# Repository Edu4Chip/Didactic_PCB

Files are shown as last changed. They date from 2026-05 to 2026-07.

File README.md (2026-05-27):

# Didactic PCB
This repository includes design files and documentation for Didactic PCBs and software for the power management microcontroller on the PCB.

## Folders
Doc: All documentation is gathered within this folder.
PCBs: KiCad projects Didactic main and wire bond PCBs.
PM_MCU_software: STM32CubeIDE project for the power management microcontroller on the PCB.

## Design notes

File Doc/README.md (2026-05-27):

# Didactic PCB V1.0 user guide 
This repository includes design files and documentation for Didactic PCBs and software for the power management microcontroller on the PCB.

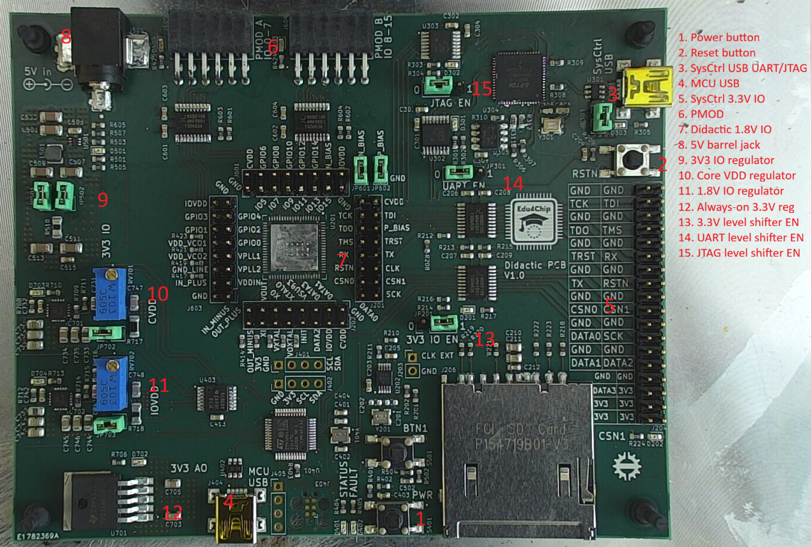
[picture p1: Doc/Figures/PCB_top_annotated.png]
 

## Power and start-up
The Didactic PCB requires external 5V source to function. The 5V can be inserted from a 5.5 mm x 2.1 mm barrel jack or from the SysCtrl Mini-USB port. Only one of these methods should be used at once. If the barrel jack and the SysCtrl Mini-USB port are used at the same time, then JP303 should be opened to disconnect the 5V power from the Mini-USB port.

### Status LED
After 5V power has been provided to the board, an LED (D303) near the SysCtrl Mini-USB port should be lit to indicate that power is being provided. LED (D702) should also be lit to indicate that always-on 3.3 V is being regulated. Finally, the Status LED (D401) should slowly blink to indicate that the microcontroller on the board is ready, and the rest of the board can be powered by pressing the PWR button (S401). After pressing the Power button, the microcontroller will enable 3.3V IO, 1.8V IO and 0.9V Core power rails and start the clock generator and finally release the reset for the Didactic chip. Successful start-up is indicated by the STATUS LED being lit and not blinking. An LED near each power rail’s source will also be lit to indicate that the power rails are enabled. 

|STATUS LED pattern  |Pattern meaning |
|---|---|
|Slowly blinking |Board is powered, but Didactic power is off |
|Rapid blinking |Didactic power is on, but fault monitoring is disabled |
|Fully on |Didactic is powered and clock enabled |

### Power monitoring
The power rails are always monitored for failure (Unless fault monitoring has been disabled). The power rails will fail if their voltage differs too much from the set amount or if too much current is being drawn from them. All power rails are immediately powered down if a failure is noticed in any of the power rails. Failure is indicated by blinking the Fault LED (D402). The failed power rail is indicated by the blinking pattern of the Fault LED (table 2). After power rail failure, the board can be repowered by pressing the PWR button.

|Fault LED blink count|Failed power rail |
|---|---|
|1 |Core |
|2 |IO |
|3 |3.3V IO |

### Votage adjustment
Voltage of IO and Core power rails can be adjusted with trimmers RV702 and RV701. It is recomended to disable power rail fault checking while adjusting the voltages and set new target voltages for each power rail after adjustment. More information about this can be found under the power monitor MCU section.

If needed, the power regulators can be disconnected from the power rails by removing the jumpers near them (JP703, JP702, JP501 and JP502). This may be needed aduring the first bring-up process for each PCB as the power rail voltages may be set incorrectly. If the Didactic chip is assembled on the PCB before bring-up, the power regulators must be disconnected and adjusted. 

## IO
### SysCtrl 3.3V IO
All SysCtrl IOs are level shifted to 3.3V and available on header J204. The signals are level shifted using bidirectional auto direction sensing level shifters. The level shifters must be enabled using the 3V3 IO EN jumper. Because of a design mistake, the level shifters are enabled when the jumper is set to 0 and disabled when the jumper is set to 1. LED D201 near the jumper will indicate when the level shifters are enabled. Level shifted SPI signals are also connected to an SD card socket.

JTAG and UART signals are also level shifted using separate unidirectional level shifters and connected to FT2232HQ USB converter. These level shifters can be enabled with UART EN (JP301) and JTAG EN (JP302) jumpers. Pinout for the FT2232HQ is shown below.

|FT2232HQ pin |Net |
|---|---|
|ADBUS0 |TCK |
|ADBUS1 |TDI |
|ADBUS2 |TDO |
|ADBUS3 |TMS |
|BDBUS0 |TX (Didactic RX) |
|BDBUS1 |RX (Didactic TX) |

### Didactic 1.8V IO
All Didactic 1.8V IO is directly accessible on pin headers J201, J202, J601 and J603. All analog pins 32-50 of Didactic are connected to ground using 0-ohm resistors. N BIAS and P BIAS are connected to ground using JP601 and JP602 jumpers.

### PMOD
GPIO signals 0-15 of the Didactic are connected to two PMOD (PMOD A and PMODB) connectors and level shifted to 3.3V using bidirectional auto direction sensing level shifters. These level sifters are always enabled. PMOD connector IO signal pinouts are shown below.

PMOD A pinoout:
|Didactic |PMOD A |
|---|---|
|GPIO0 |IO1 |
|GPIO1 |IO2 |
|GPIO2 |IO3 |
|GPIO3 |IO4 |
|GPIO4 |IO5 |
|GPIO5 |IO6 |
|GPIO6 |IO7 |
|GPIO7 |IO8 |

PMOD B pinoout:
|Didactic |PMOD B |
|---|---|
|GPIO8 |IO1 |
|GPIO9 |IO2 |
|GPIO10 |IO3 |
|GPIO11 |IO4 |
|GPIO12 |IO5 |
|GPIO13 |IO6 |
|GPIO14 |IO7 |
|GPIO15 |IO8 |

## Power monitor MCU
Microcontroller on the board is used to monitor and sequence the power rails and control the clock generator. The Didactic can be started by pressing the PWR button or the start-up process can be controlled using the microcontrollers virtual COM port. The COM port can be accessed by connecting a Mini-USB cable to the MCU USB port.

### Virtual COM port
Any virtual terminal software can be used to connect to Virtual COM port. Baud rate can also be freely chosen.

The microcontroller will continuously print the voltage and current of all the power rails. The virtual terminal window should be made big enough so that a full line of text can fit without line changes. Commands can be typed into the virtual terminal, and all commands must be ended by pressing enter. Pressing enter will also always reprint the command list. Configuration for all power rails is shown at the bottom of the terminal and the bottom most line is updated three times a second and it shows the current voltage and power consumption of the power rails.

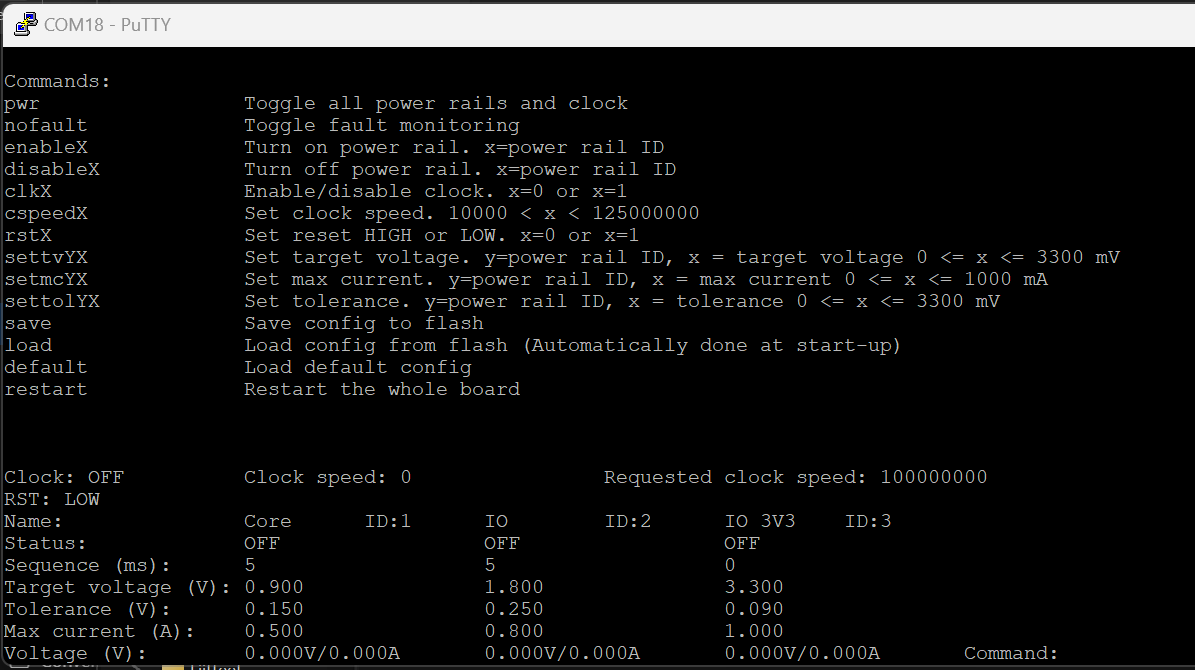
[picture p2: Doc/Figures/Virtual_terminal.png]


### Commands
Power rails and the clock can be controlled by writing commands to the virtual terminal. All supported commands are shown below.

|Command |Parameters |Explanation |
|---|---|---|
|pwr | |Turns on/off all the power rails and clock. Same as pressing the PWR button |
|nofault | |Disables/enables fault checking for all power rails. Status LED will blink quickly when power is enabled, and fault checking is disabled |
|enableX |X = power rail ID |Enabled power rail* |
|disableX |X = power rail ID |Disable power rail* |
|clkX |X = 0 or X = 1 |Enabled or disable clock. 1 = enable |
|cspeed |10000 < X < 125000000 |Set requested clock speed. clk1 command must be sent after this command to enable clock with requested speed |
|rstX |X = 0 or X = 1 |Set Didactic reset LOW or HIGH, LOW = reset |
|settvYX |Y = power rail ID, 0 mV <= X <= 3300 mV|Set power rail’s target voltage |
|setmcYX |Y = power rail ID, 0 mA <= X <= 1000 mA|Set power rail’s maximum current |
|settolYX |Y = power rail ID, 0 mV <= X <= 3300 mV|Set power rail’s tolerance to voltage difference between target and actual voltage |
|save | |Save current config to Flash |
|load | |Load config from flash |
|default | |Load default config |
|restart | |Shutdown all power rails and restart the MCU |

*IO and Core power rails source their power from 3.3V IO power rails, so they cannot be powered before 3.3V IO power rails. IO and Core can be enabled before 3.3V IO power rails but they will be powered only after 3.3V IO has been powered. 

### Programming
The microcontroller can be programmed using ST-LINK debugger using SWD interface. This can be done using 4-pin pin header (J405) or 6-pin TC2030 Tag-Connect cable.

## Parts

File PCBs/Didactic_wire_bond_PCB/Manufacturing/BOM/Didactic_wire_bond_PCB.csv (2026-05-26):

Reference | Qty | Value | DNP | Exclude from BOM | Exclude from Board | Footprint | Datasheet
C101,C102,C103,C104,C105,C106,C107,C108 | 8 | 100n |  |  |  | Capacitor_SMD:C_0402_1005Metric | ~
J101 | 1 | 2118714-2 |  |  |  | SoC_Hub_kicad_footprint_library:TE_2118714-2
J201,J202,J601,J603 | 4 | Conn_02x08_Odd_Even | DNP |  |  | Connector_PinHeader_2.54mm:PinHeader_2x08_P2.54mm_Vertical | ~
U101 | 1 | ~ |  |  |  | SoC_Hub_kicad_footprint_library:Didactic_WB

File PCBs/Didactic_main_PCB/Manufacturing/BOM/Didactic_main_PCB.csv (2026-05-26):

Reference | Value | Footprint | Qty | DNP | MANUFACTURER_PART_NUMBER
C201,C202 | 4p | Capacitor_SMD:C_0603_1608Metric | 2 | DNP
C203,C204,C205,C206,C207,C208,C209,C212,C301,C302,C303,C304,C307,C308,C310,C311,C312,C314,C316,C317,C318,C319,C320,C321,C403,C404,C405,C406,C407,C408,C409,C410,C413,C502,C505,C515,C601,C602,C603,C604,C711,C712,C713,C714,C715,C716,C717,C718,C721,C722,C723,C724,C725,C726,C727,C728,C731,C743 | 100n | Capacitor_SMD:C_0603_1608Metric | 58 |  | GPC0603104
C210,C211,C703,C705,C719,C720,C729,C730,C734,C735,C737,C738,C740,C741,C745,C746,C747,C748 | 10u | Capacitor_SMD:C_0805_2012Metric | 18 |  | GPC0805106-25
C305,C306,C401,C402 | 10p | Capacitor_SMD:C_0603_1608Metric | 4 |  | GPC0603100
C309,C313,C315,C411,C412 | 4.7u | Capacitor_SMD:C_0603_1608Metric | 5 |  | GPC0603475-10
C501,C503,C507,C509,C511,C513 | 22u | Capacitor_SMD:C_1206_3216Metric | 6 |  | CL31A226KAHNNNE
C732,C742 | 10n | Capacitor_SMD:C_0603_1608Metric | 2 |  | GPC0603103
C733,C736,C739,C744 | 47u | Capacitor_SMD:C_0805_2012Metric | 4 |  | GPC0805476-6.3
D201,D202,D301,D302,D303,D401,D402,D403,D404,D501,D702,D703,D704 | LED | LED_SMD:LED_0603_1608Metric | 13 |  | APHD1608LSURCK
IC201,IC202,IC601,IC602 | NXB0108PWJ | SoC_Hub_kicad_footprint_library:NXB0108PWJ | 4 |  | NXB0108PWJ
IC701,IC702 | AP7179DSKZ20-13 | SoC_Hub_kicad_footprint_library:QFN50P350X350X80-21N-D | 2 |  | AP7179DSKZ20-13
J201,J202,J601,J603 | Conn_02x08_Odd_Even | Connector_PinHeader_2.54mm:PinHeader_2x08_P2.54mm_Vertical | 4 |  | 77313-101-16LF
J203 | Conn_01x02_Pin | Connector_PinHeader_2.54mm:PinHeader_1x02_P2.54mm_Vertical | 1 |  | 61300211121
J204 | Conn_02x18_Odd_Even | Connector_PinHeader_2.54mm:PinHeader_2x18_P2.54mm_Vertical | 1 |  | 77313-101-36LF
J206 | 10067847-001RLF | AMPHENOL_10067847-001RLF | 1 |  | 10067847-001RLF
J301,J404 | 690-005-299-043 | Headsail_footprints:EDAC_690-005-299-043 | 2 |  | 690-005-299-043
J401,J402 | Conn_01x04_Pin | Connector_PinHeader_2.54mm:PinHeader_1x04_P2.54mm_Vertical | 2 | DNP | 77311-424-04LF
J405 | Conn_01x04_Pin | Connector_PinHeader_2.54mm:PinHeader_1x04_P2.54mm_Vertical | 1 |  | 77311-424-04LF
J501 | PJ-036AH-SMT-TR | Headsail_footprints:CUI_PJ-036AH-SMT-TR | 1 |  | PJ-036AH-SMT-TR
J604,J605 | SSW-106-02-T-D-RA | SoC_Hub_kicad_footprint_library:SAMTEC_SSW-106-02-T-D-RA | 2 |  | SSW-106-02-T-D-RA
JP201,JP301,JP302 | Jumper_3_Open | Connector_PinHeader_2.54mm:PinHeader_1x03_P2.54mm_Vertical | 3 |  | 61300311121
JP303,JP501,JP502,JP601,JP602,JP702,JP703 | Jumper_2_Bridged | Connector_PinHeader_2.54mm:PinHeader_1x02_P2.54mm_Vertical | 7 |  | 61300211121
L501 | 74404032015 | SoC_Hub_kicad_footprint_library:WE-LQS_3015 | 1 |  | 74404032015
R201,R202,R206,R208,R215,R216,R302,R304,R306,R307,R310,R402,R403,R503,R504,R505,R507,R603,R604,R708,R709,R711,R712,R714,R715,R716 | 10k | Resistor_SMD:R_0603_1608Metric | 26 |  | GPR060310K
R203,R204,R205,R207,R218,R219,R220,R221,R222,R223 | 56k2 | Resistor_SMD:R_0603_1608Metric | 10 |  | CPF0603F56K2C1
R209,R213,R214,R217,R224,R301,R303,R305,R309,R311,R312,R401,R404,R405,R424,R425,R501,R502,R601,R602,R706,R710,R713 | 1k | Resistor_SMD:R_0603_1608Metric | 23 |  | GPR06031K
R210 | 0 | Resistor_SMD:R_0603_1608Metric | 1 | DNP | GPR06030R
R211,R212,R406,R407,R408,R409,R410,R411,R412,R413,R414,R415,R416,R417,R418,R419,R420,R421,R422,R423 | 0 | Resistor_SMD:R_0603_1608Metric | 20 |  | GPR06030R
R308 | 12k | Resistor_SMD:R_0603_1608Metric | 1 |  | GPR060312K
R510,R718 | 16m | Resistor_SMD:R_1206_3216Metric | 2 |  | ERJ-8CWFR016V
R605 | 45.3k | Resistor_SMD:R_0603_1608Metric | 1 |  | CPF0603F45K3C1
R717 | 33m | Resistor_SMD:R_1206_3216Metric | 1 |  | ERJ-8CWFR033V
RV701,RV702 | PV36W103C01B00 | SoC_Hub_kicad_footprint_library:TRIM_PV36W103C01B00 | 2 |  | PV36W103C01B00
S201,S401,S501 | TL3301TF160QG | Headsail_footprints:SW_TL3301TF160QG | 3 |  | TL3301TF160QG
U201 | ~ | SoC_Hub_kicad_footprint_library:Didactic_QFN-80_EP_12x12_Pitch0.5mm | 1
U202 | SI5351A-B-GT | SoC_Hub_kicad_footprint_library:MSOP10_SI5351_3X3-0P5_SKY | 1 |  | SI5351A-B-GT
U301,U402 | USBLC6-2SC6 | Package_TO_SOT_SMD:SOT-23-6 | 2 |  | USBLC6-2SC6
U302,U303 | SN74AVC4T774PWR | SoC_Hub_kicad_footprint_library:SOP65P640X120-16N | 2 |  | SN74AVC4T774PWR
U304 | FT2232HQ | Headsail_footprints:QFN50P900X900X100-65N | 1 |  | FT2232HQ
U305 | 93LC56BT_SN | Headsail_footprints:SOIC127P600X175-8N | 1 |  | 93LC56BT/SN
U401 | STM32G431CBT6 | LQFP48-7x7mm | 1 |  | STM32G431CBT6
U403 | INA4180A4IPWR | Headsail_footprints:SOP65P640X120-14N | 1 |  | INA4180A4IPWR
U501 | TPS564255DRLR | TPS564242DRLR_TEX | 1 |  | TPS564255DRLR
U701 | TPS7A4533KTTR | SoC_Hub_kicad_footprint_library:VREG_TPS79625KTTR | 1 |  | TPS7A4533KTTR
Y201,Y401 | ECS-250-8-33B-CKM-TR | SoC_Hub_kicad_footprint_library:XTAL_ECS-250-8-33B-CKM-TR | 2 |  | ECS-250-8-33B-CKM-TR
Y301 | ECS-120-8-33-JGN-TR3 | Headsail_footprints:XTAL_ECS-120-8-33-JGN-TR3 | 1 |  | ECS-120-8-33-JGN-TR3

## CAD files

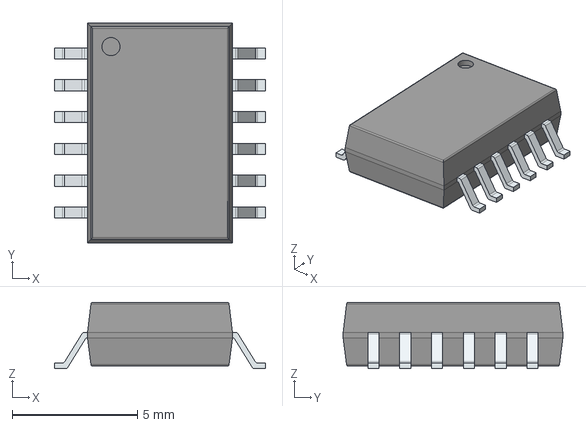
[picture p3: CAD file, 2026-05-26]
PCBs/Didactic_component_library/3D/218-6LPST.stp
8.44 x 8.79 x 2.65 mm
PinsArrayLR

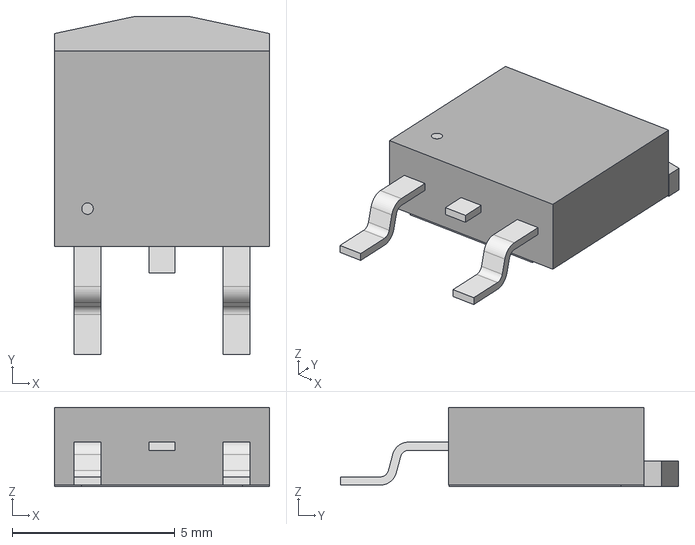
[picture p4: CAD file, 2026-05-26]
PCBs/Didactic_component_library/3D/TO-252-3_6P6X6P1_DIO.step
6.60 x 10.4 x 2.44 mm

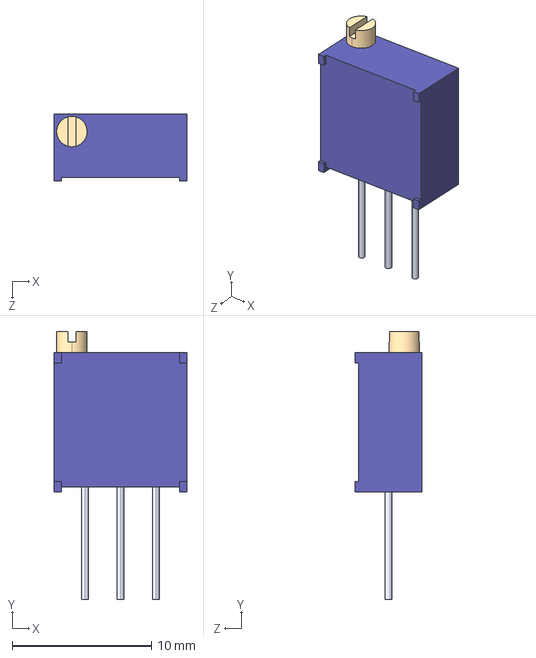
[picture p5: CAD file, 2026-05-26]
PCBs/Didactic_component_library/3D/PV36W103C01B00.step
9.53 x 19.3 x 4.83 mm

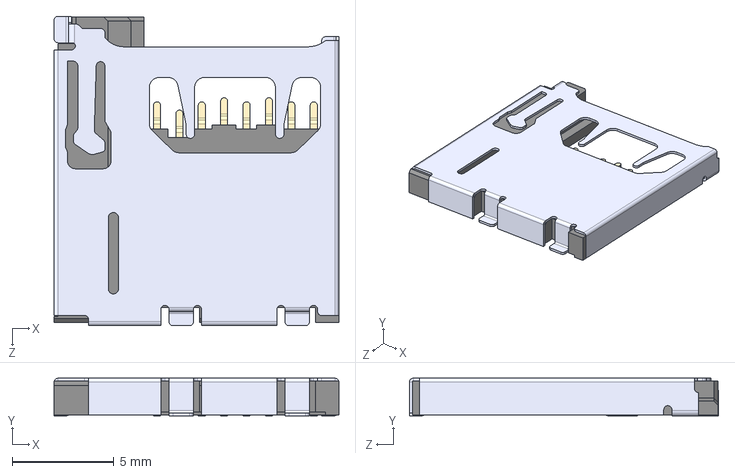
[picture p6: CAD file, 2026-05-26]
PCBs/Didactic_component_library/3D/2908-05WB-MG.step
14.0 x 1.85 x 15.2 mm

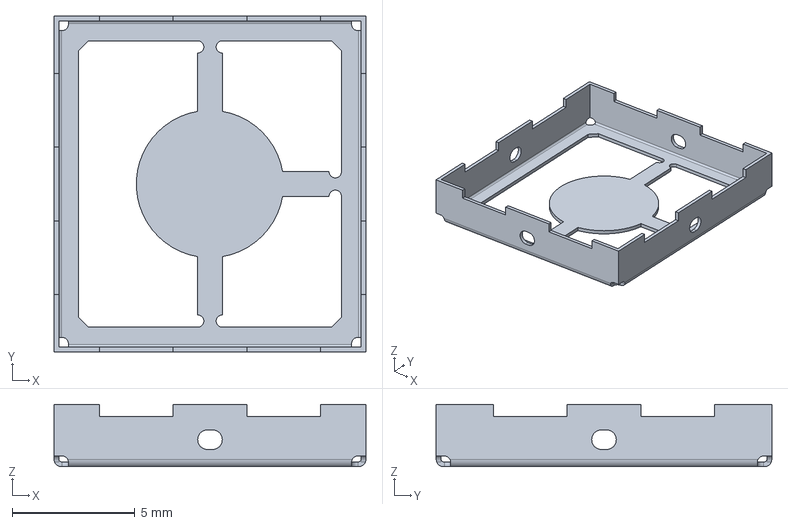
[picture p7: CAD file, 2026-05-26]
PCBs/Didactic_component_library/3D/2118714-2.step
12.7 x 13.7 x 2.54 mm

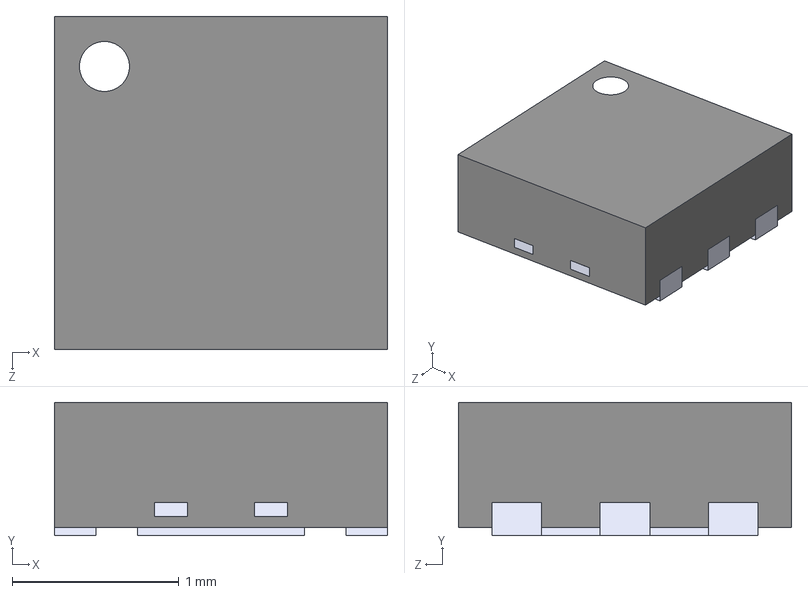
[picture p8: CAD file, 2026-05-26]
PCBs/Didactic_component_library/3D/TLV75709PDRVR.step
2.00 x 0.8 x 2.00 mm

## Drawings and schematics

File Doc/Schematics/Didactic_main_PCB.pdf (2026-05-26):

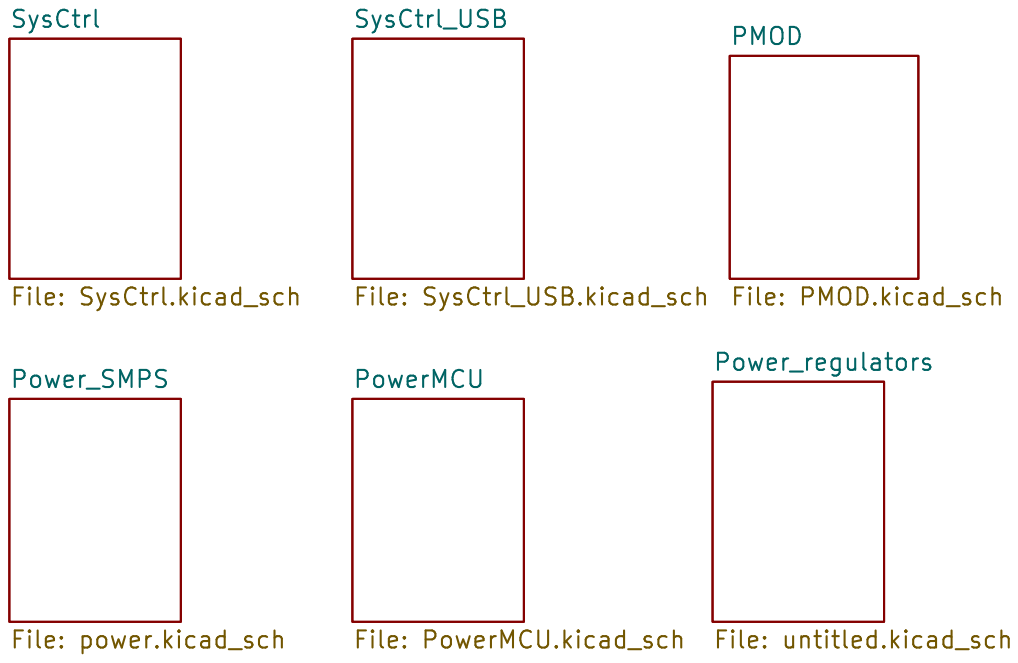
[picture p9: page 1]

Roope Keskinen / roope.r.keskinen@tuni.fi
File: Didactic.kicad_sch Sheet: / TAU

Id: 1/7 Title: Didactic PCB

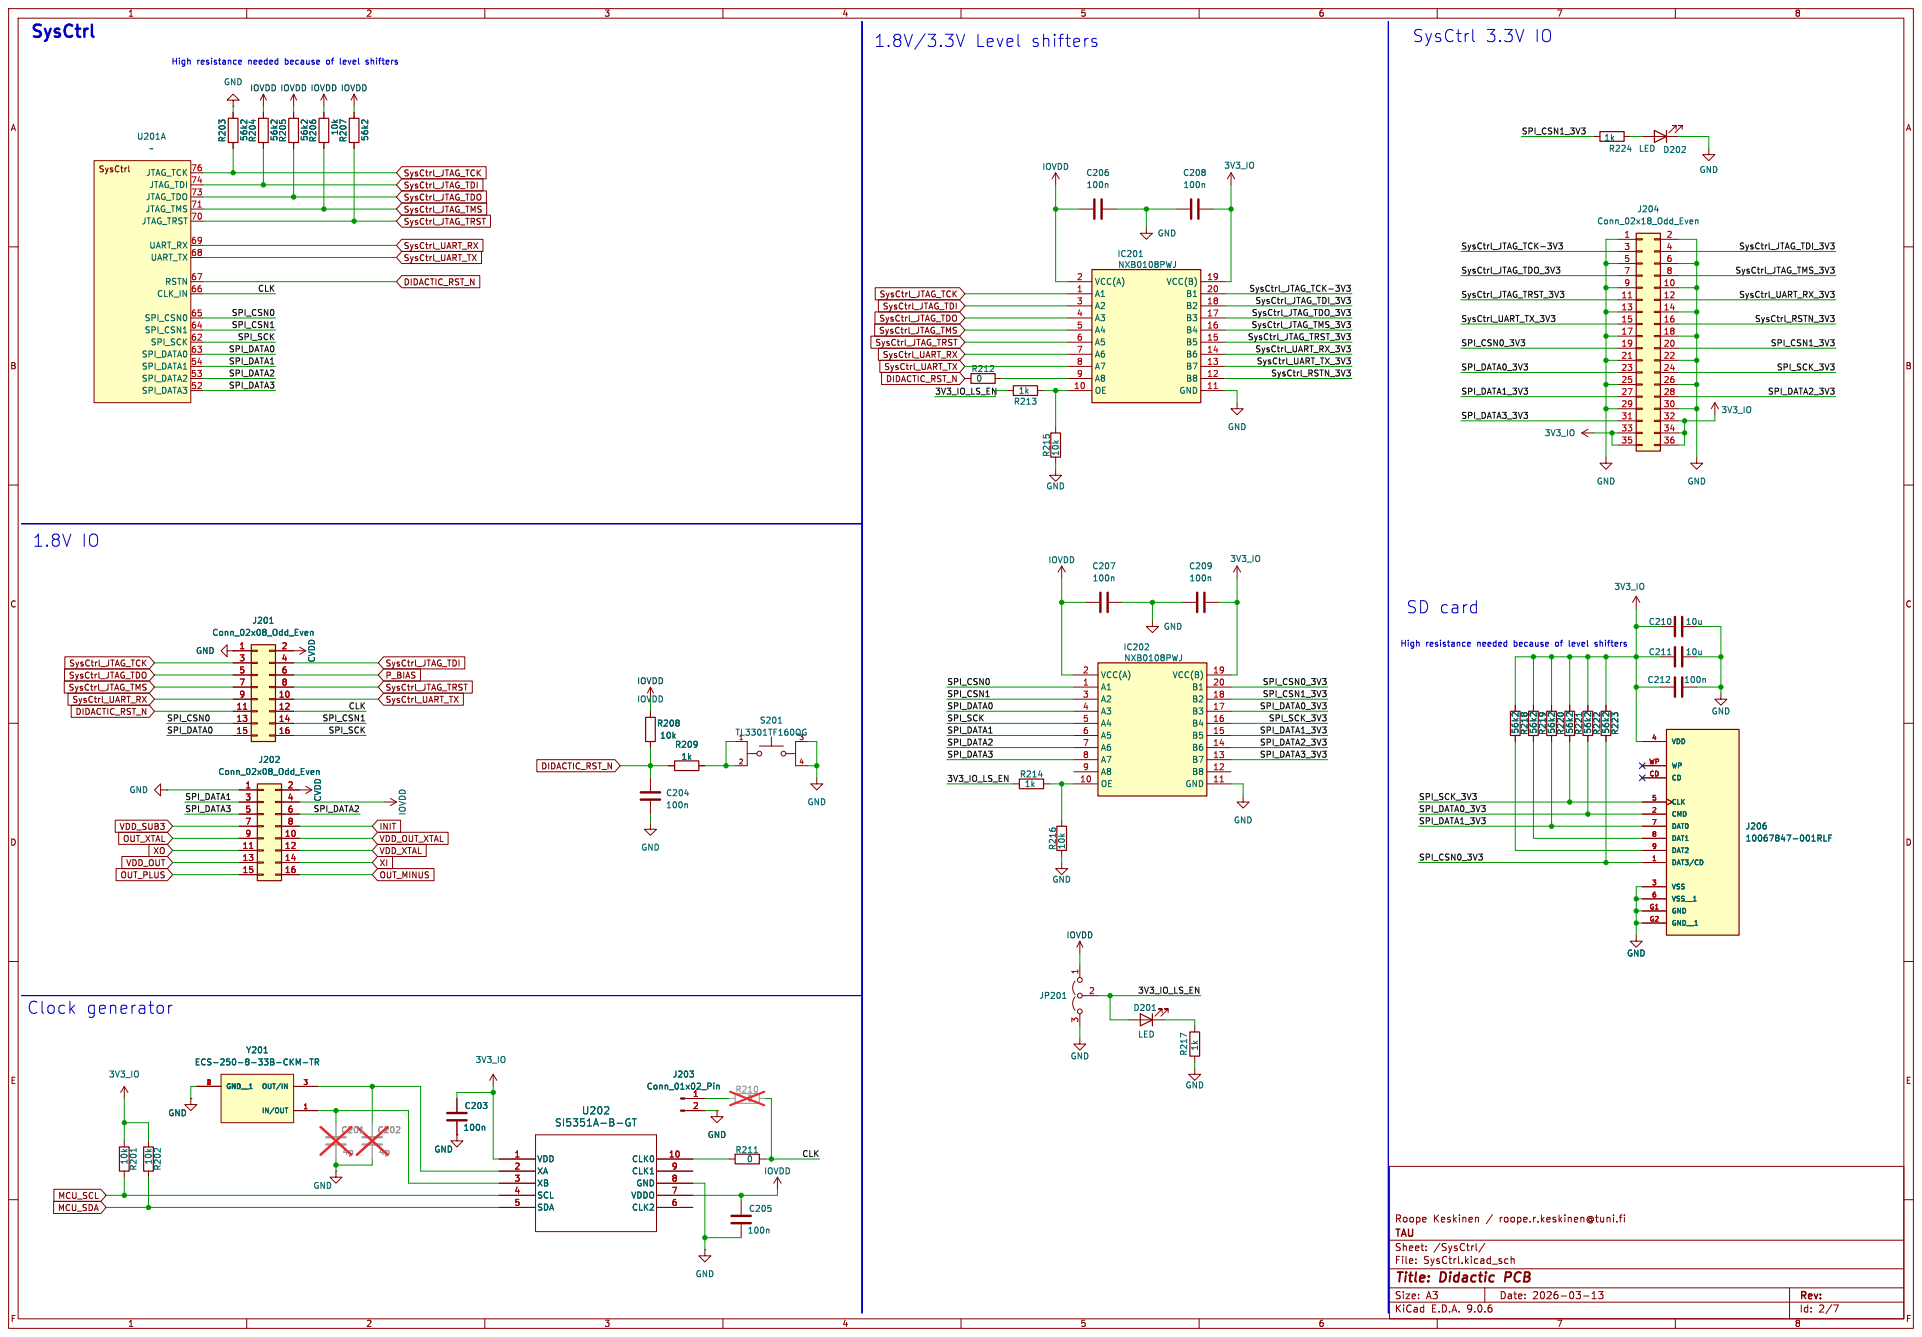
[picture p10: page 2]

File: SysCtrl.kicad_sch Sheet: /SysCtrl/ TAU

Id: 2/7 Title: Didactic PCB

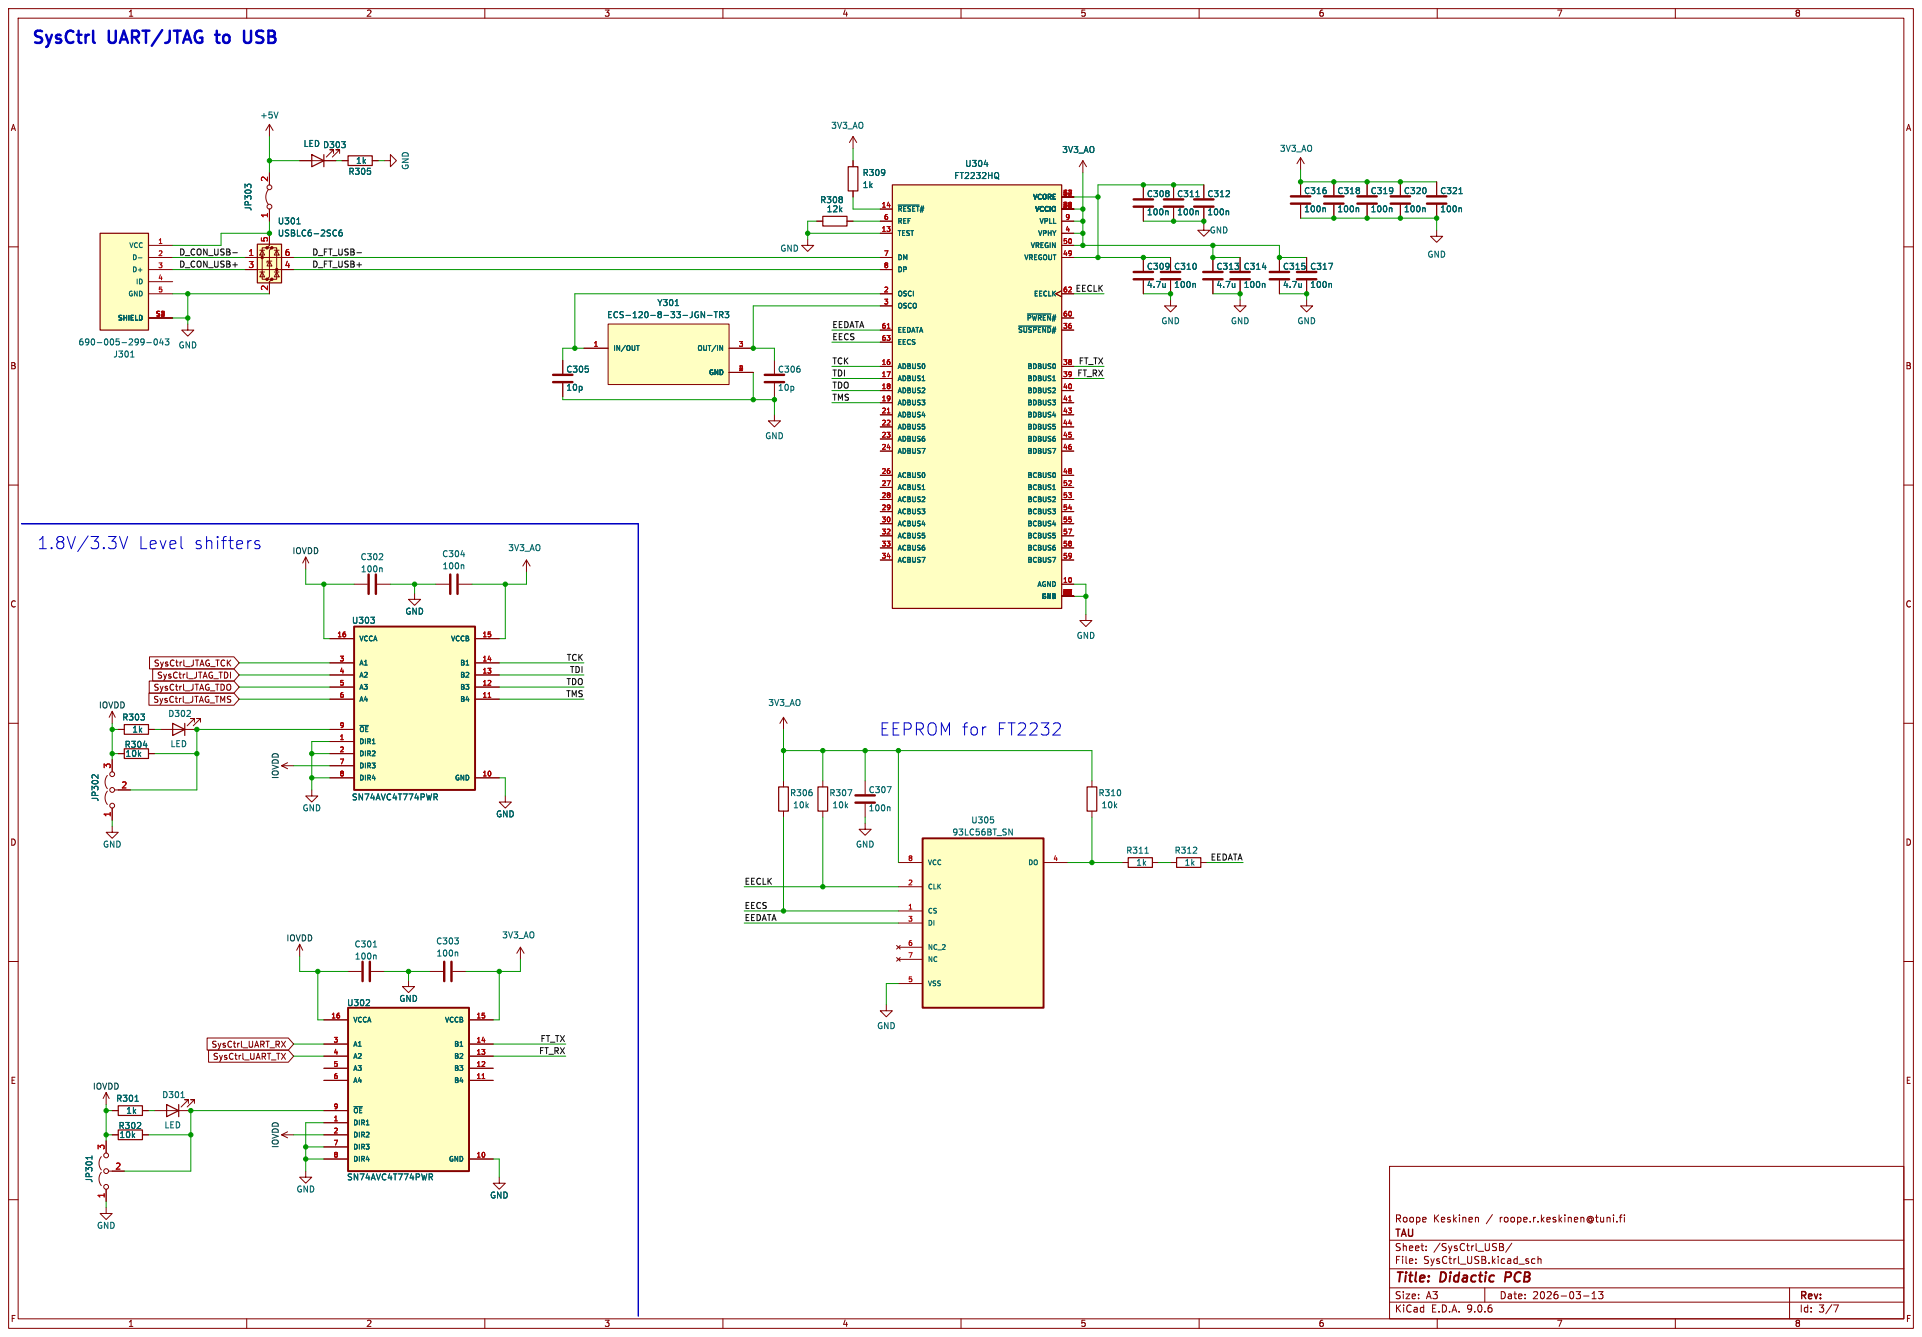
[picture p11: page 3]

SysCtrl UART/JTAG to USB

Id: 3/7 Title: Didactic PCB

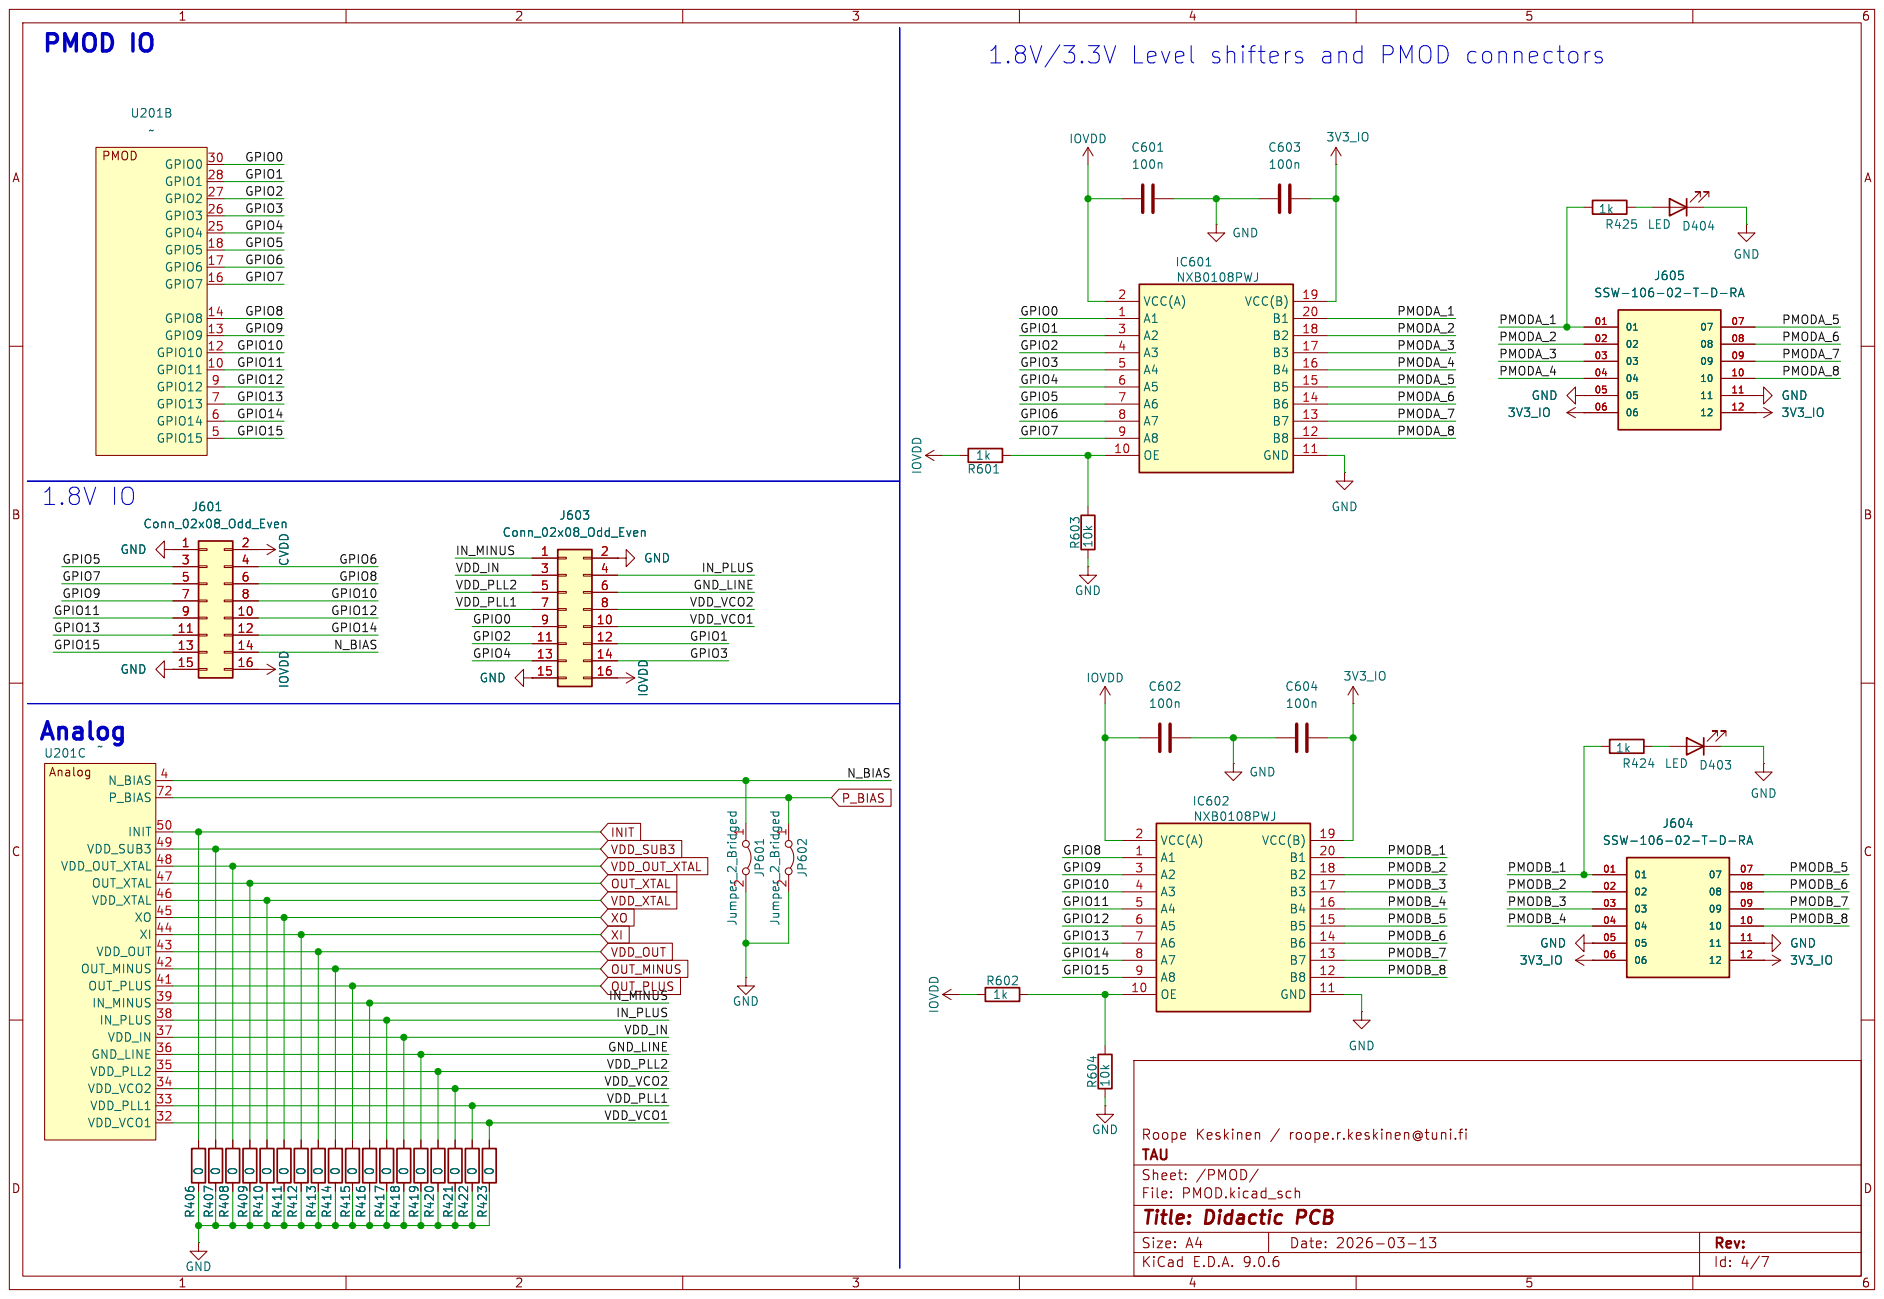
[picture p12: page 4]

0 GND GND GND R604 10k GND

Roope Keskinen / roope.r.keskinen@tuni.fi
File: PMOD.kicad_sch Sheet: /PMOD/ TAU

Id: 4/7 Title: Didactic PCB

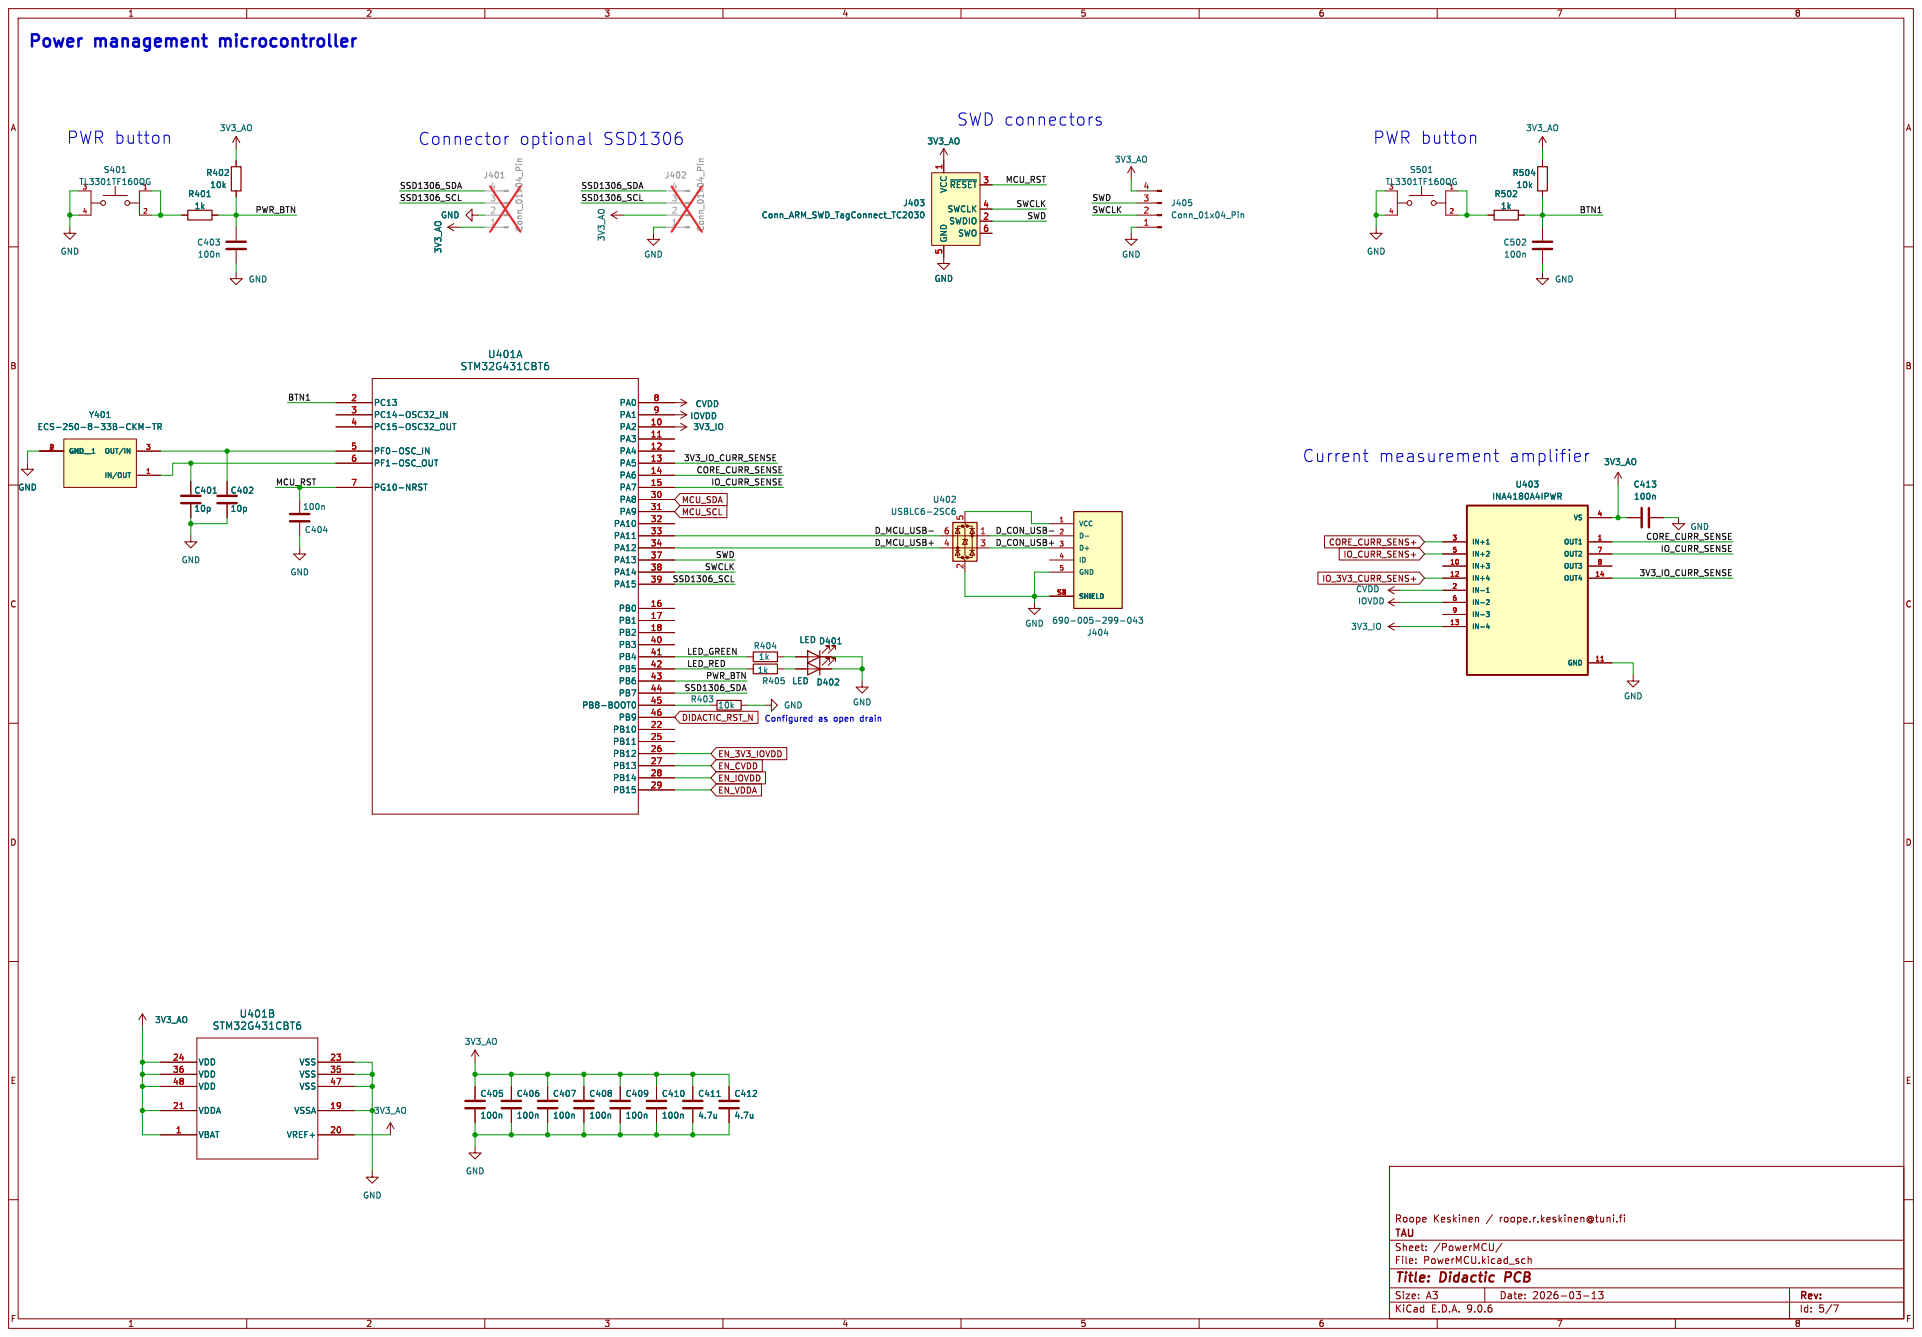
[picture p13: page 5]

5 ~{RESET}3 SWCLK 4 SWDIO 2 SWO 6

Id: 5/7 Title: Didactic PCB

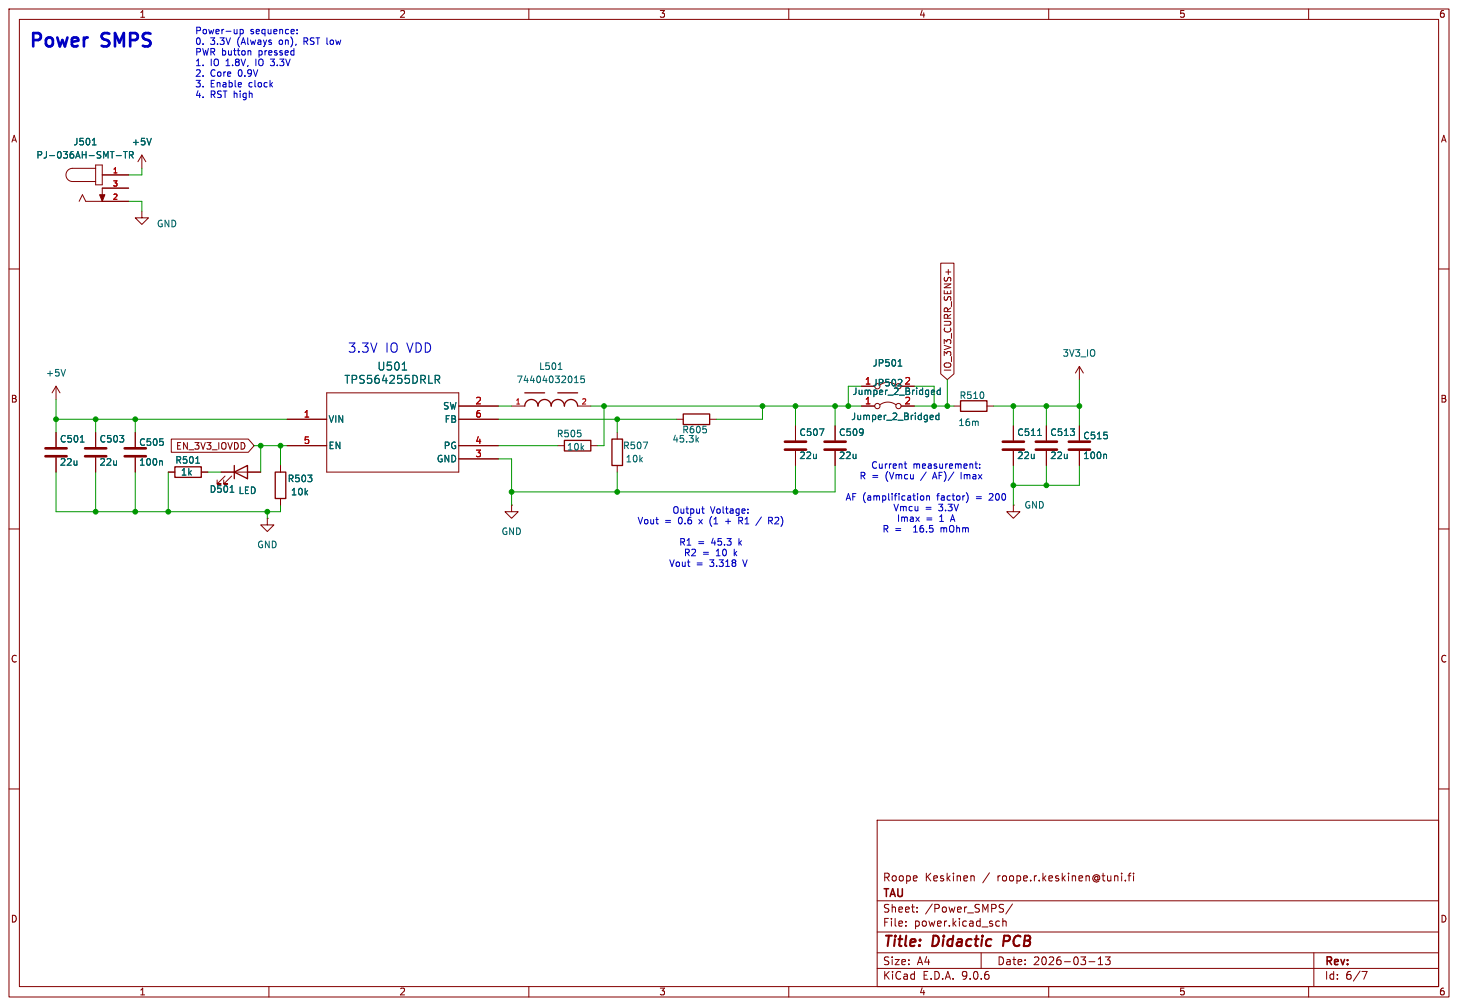
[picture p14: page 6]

PWR button pressed
2. Core 0.9V
3. Enable clock 4. RST high

Output Voltage: Vout = 0.6 x (1 + R1 / R2) R1 = 45.3 k R2 = 10 k Vout = 3.318 V 3.3V IO VDD
22u U501 TPS564255DRLR

Roope Keskinen / roope.r.keskinen@tuni.fi R605

File: power.kicad_sch Sheet: /Power_SMPS/ TAU

Id: 6/7 Title: Didactic PCB

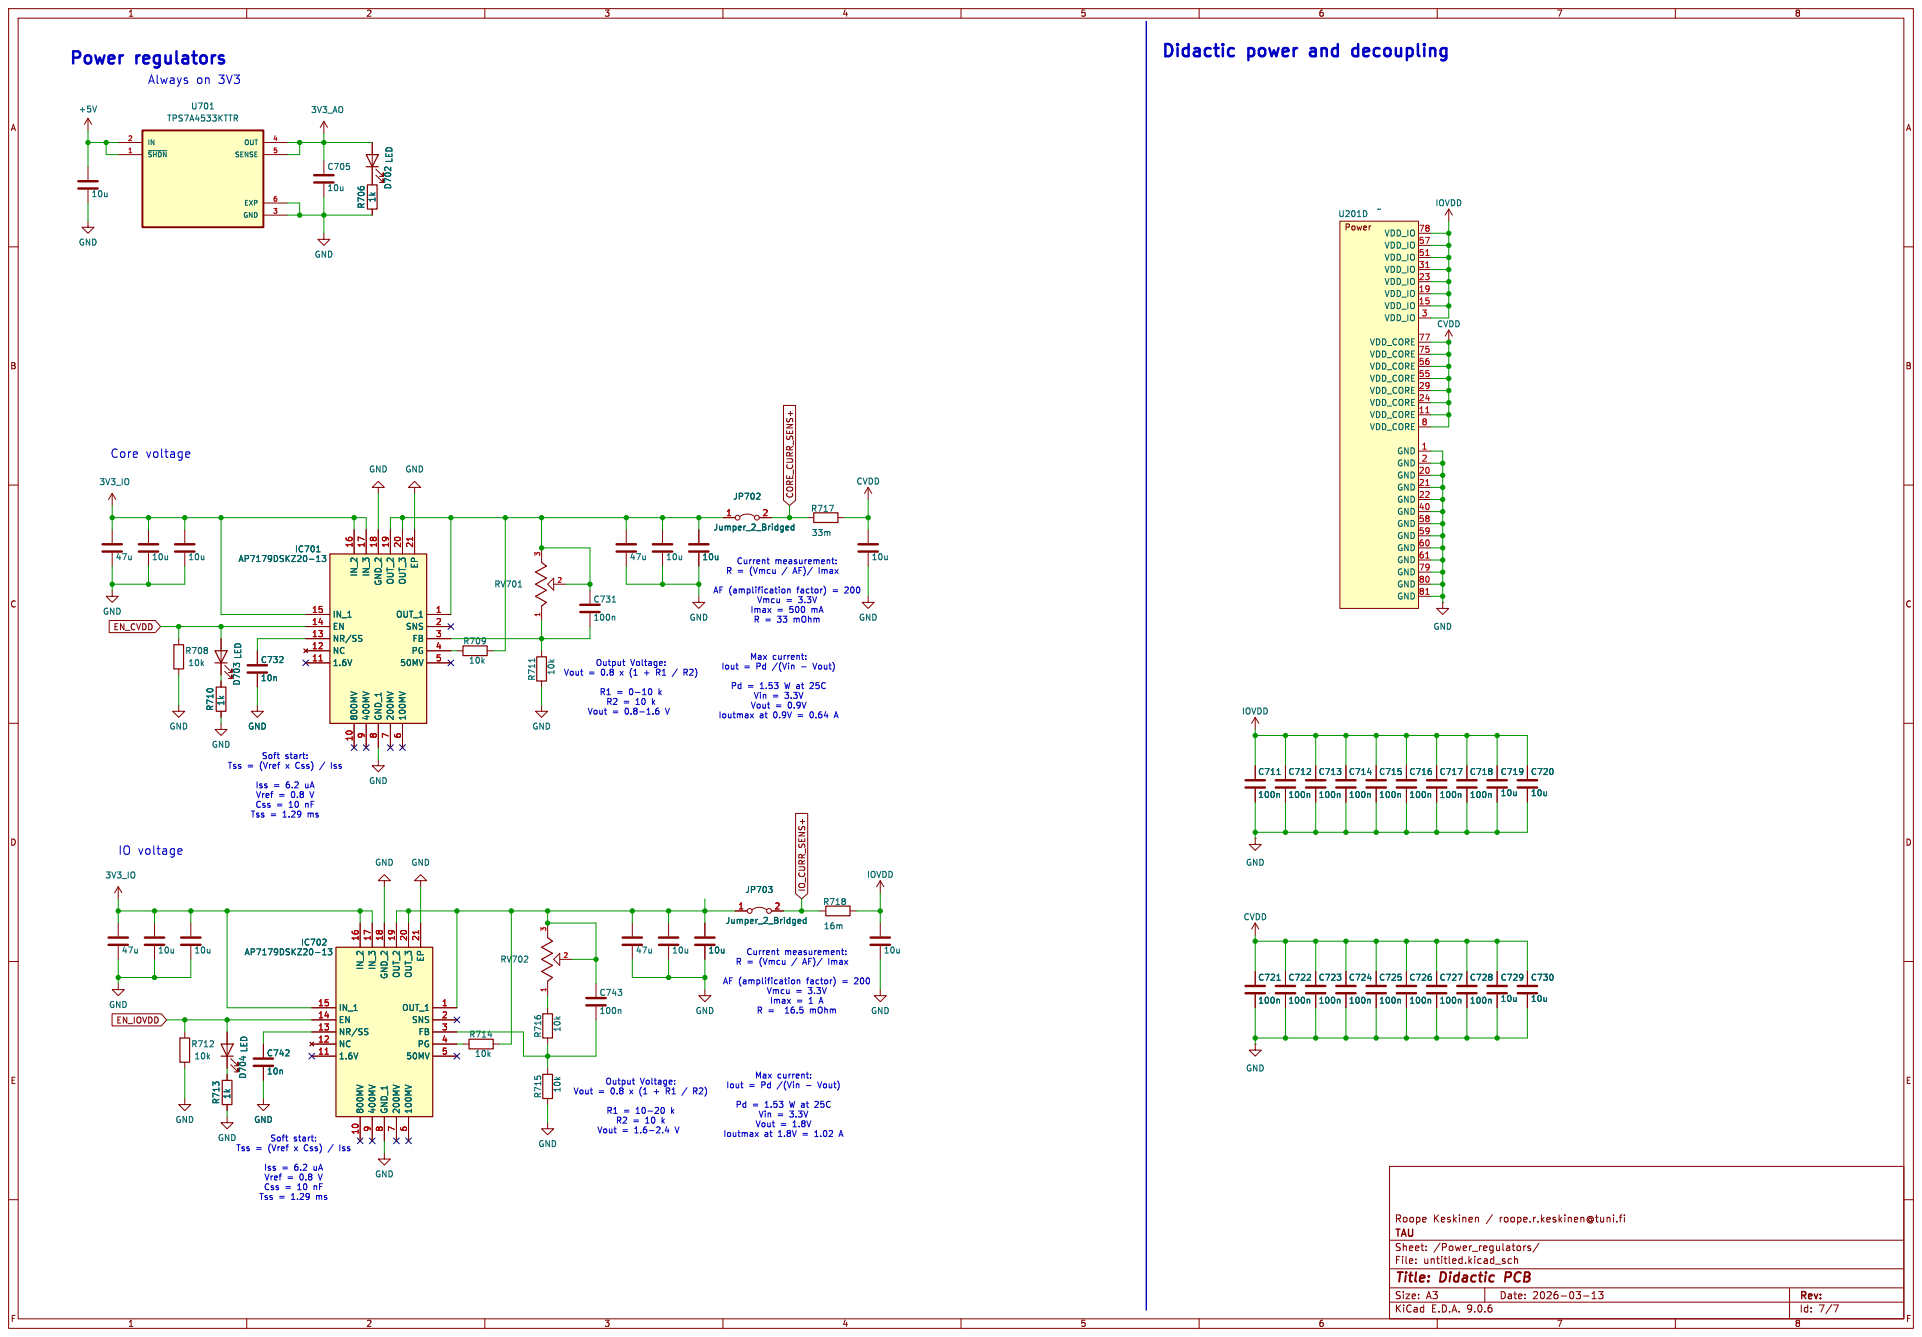
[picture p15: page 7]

Soft start: Tss = (Vref x Css) / Iss

File: untitled.kicad_sch Sheet: /Power_regulators/ TAU

Id: 7/7 Title: Didactic PCB

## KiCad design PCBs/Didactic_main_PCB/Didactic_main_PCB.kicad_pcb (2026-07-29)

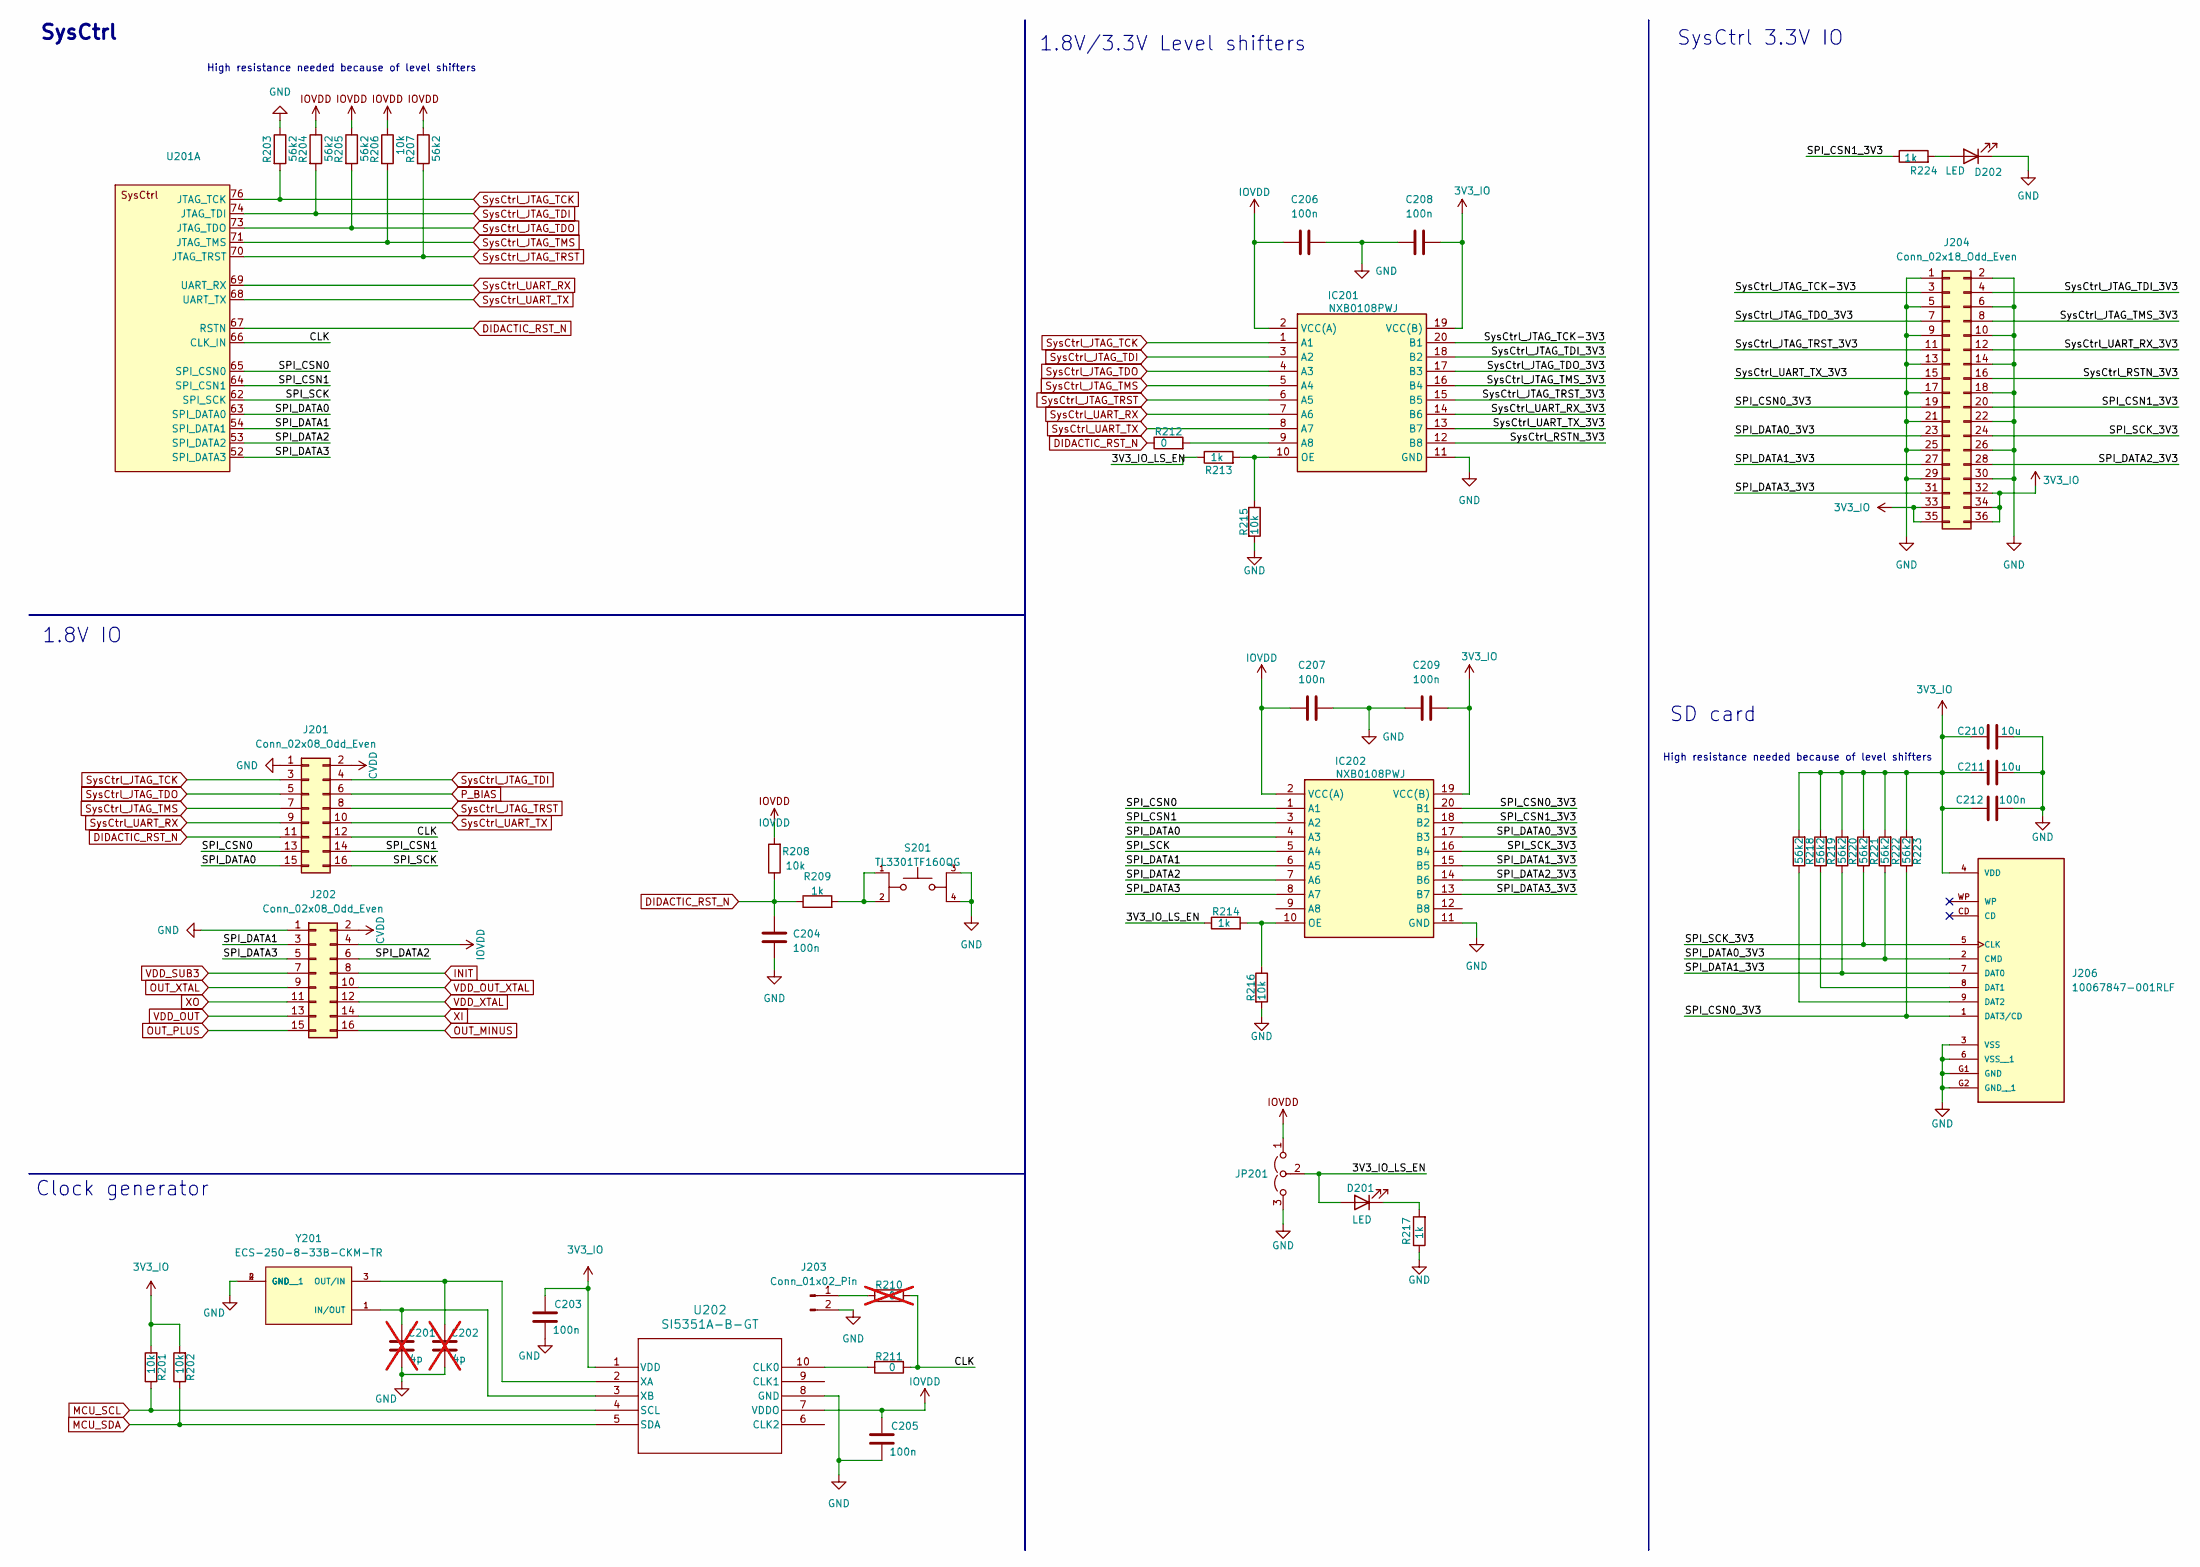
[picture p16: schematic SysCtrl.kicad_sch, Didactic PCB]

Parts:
C201, C202: 4p; C_0603_1608Metric; not fitted
C203, C204, C205, C206, C207, C208, C209, C212: 100n; C_0603_1608Metric; MANUFACTURER_PART_NUMBER GPC0603104
C210, C211: 10u; C_0805_2012Metric; MANUFACTURER_PART_NUMBER GPC0805106-25
D201, D202: LED; LED_0603_1608Metric; MANUFACTURER_PART_NUMBER APHD1608LSURCK
IC201, IC202: NXB0108PWJ; Mouser Part Number 771-NXB0108PWJ
J201, J202: Conn_02x08_Odd_Even; PinHeader_2x08_P2.54mm_Vertical; MANUFACTURER_PART_NUMBER 77313-101-16LF
J203: Conn_01x02_Pin; PinHeader_1x02_P2.54mm_Vertical; MANUFACTURER_PART_NUMBER 61300211121
J204: Conn_02x18_Odd_Even; PinHeader_2x18_P2.54mm_Vertical; MOUSER_PART_NUMBER 77313-101-36LF
J206: 10067847-001RLF; AMPHENOL_10067847-001RLF; PARTREV K
JP201: Jumper_3_Open; PinHeader_1x03_P2.54mm_Vertical; MANUFACTURER_PART_NUMBER 61300311121
R201, R202, R206, R208, R215, R216: 10k; R_0603_1608Metric; MANUFACTURER_PART_NUMBER GPR060310K
R203, R204, R205, R207, R218, R219, R220, R221, R222, R223: 56k2; R_0603_1608Metric; MANUFACTURER_PART_NUMBER CPF0603F56K2C1
R209, R213, R214, R217, R224: 1k; R_0603_1608Metric; MANUFACTURER_PART_NUMBER GPR06031K
R210: 0; R_0603_1608Metric; MANUFACTURER_PART_NUMBER GPR06030R; not fitted
R211, R212: 0; R_0603_1608Metric; MANUFACTURER_PART_NUMBER GPR06030R
S201: TL3301TF160QG; SW_TL3301TF160QG; PARTREV E
U201: Didactic_QFN-80_EP_12x12_Pitch0.5mm
U202: SI5351A-B-GT; MSOP10_SI5351_3X3-0P5_SKY; MANUFACTURER_PART_NUMBER SI5351A-B-GT
Y201: ECS-250-8-33B-CKM-TR; XTAL_ECS-250-8-33B-CKM-TR; MANUFACTURER_PART_NUMBER ECS-250-8-33B-CKM-TR

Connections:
3V3_IO: C203.2, C208.2, C209.2, C210.1, C211.1, C212.1, IC201.19 (VCC(B)), IC202.19 (VCC(B)), J204.32, J204.33, J204.34, J204.35, J204.36, J206.4 (VDD), R201.2, R202.2, R218.2, R219.2, R220.2, R221.2, R222.2, R223.2, U202.1 (VDD); also elsewhere on the board
/SysCtrl/3V3_IO_LS_EN: D201.2 (A), JP201.2 (C), R213.1, R214.1
/SysCtrl/CLK: J201.12, R210.1, R211.1, U201.66 (CLK_IN)
/SysCtrl/SPI_CSN0: IC202.1 (A1), J201.13, U201.65 (SPI_CSN0)
/SysCtrl/SPI_CSN0_3V3: IC202.20 (B1), J204.19, J206.1 (DAT3/CD), R223.1
/SysCtrl/SPI_CSN1: IC202.3 (A2), J201.14, U201.64 (SPI_CSN1)
/SysCtrl/SPI_CSN1_3V3: IC202.18 (B2), J204.20, R224.1
/SysCtrl/SPI_DATA0: IC202.4 (A3), J201.15, U201.63 (SPI_DATA0)
/SysCtrl/SPI_DATA0_3V3: IC202.17 (B3), J204.23, J206.2 (CMD), R222.1
/SysCtrl/SPI_DATA1: IC202.6 (A5), J202.3, U201.54 (SPI_DATA1)
/SysCtrl/SPI_DATA1_3V3: IC202.15 (B5), J204.27, J206.7 (DAT0), R220.1
/SysCtrl/SPI_DATA2: IC202.7 (A6), J202.6, U201.53 (SPI_DATA2)
/SysCtrl/SPI_DATA2_3V3: IC202.14 (B6), J204.28
/SysCtrl/SPI_DATA3: IC202.8 (A7), J202.5, U201.52 (SPI_DATA3)
/SysCtrl/SPI_DATA3_3V3: IC202.13 (B7), J204.31
/SysCtrl/SPI_SCK: IC202.5 (A4), J201.16, U201.62 (SPI_SCK)
/SysCtrl/SPI_SCK_3V3: IC202.16 (B4), J204.24, J206.5 (CLK), R221.1
/SysCtrl/SysCtrl_JTAG_TCK-3V3: IC201.20 (B1), J204.3
/SysCtrl/SysCtrl_JTAG_TDI_3V3: IC201.18 (B2), J204.4
/SysCtrl/SysCtrl_JTAG_TDO_3V3: IC201.17 (B3), J204.7
/SysCtrl/SysCtrl_JTAG_TMS_3V3: IC201.16 (B4), J204.8
/SysCtrl/SysCtrl_JTAG_TRST_3V3: IC201.15 (B5), J204.11
/SysCtrl/SysCtrl_RSTN_3V3: IC201.12 (B8), J204.16
/SysCtrl/SysCtrl_UART_RX_3V3: IC201.14 (B6), J204.12
/SysCtrl/SysCtrl_UART_TX_3V3: IC201.13 (B7), J204.15
CVDD: J201.2, J202.2; also elsewhere on the board
DIDACTIC_RST_N: C204.1, J201.11, R208.1, R209.1, R212.1, U201.67 (RSTN); also elsewhere on the board
GND: C201.1, C202.1, C203.1, C204.2, C205.1, C206.2, C207.2, C208.1, C209.1, C210.2, C211.2, C212.2, D202.1 (K), IC201.11 (GND), IC202.11 (GND), J201.1, J202.1, J203.2, J204.1, J204.2, J204.5, J204.6, J204.9, J204.10, J204.13, J204.14, J204.17, J204.18, J204.21, J204.22, J204.25, J204.26, J204.29, J204.30, J206.3 (VSS), J206.6 (VSS__1), J206.G1 (GND), J206.G2 (GND__1), JP201.3 (B), R203.1, R215.2, R216.2, R217.1, S201.3, S201.4, U202.8 (GND), Y201.2 (GND), Y201.4 (GND__1); also elsewhere on the board
INIT: J202.8; also elsewhere on the board
IOVDD: C205.2, C206.1, C207.1, IC201.2 (VCC(A)), IC202.2 (VCC(A)), J202.4, JP201.1 (A), R204.1, R205.1, R206.1, R207.1, R208.2, U202.7 (VDDO); also elsewhere on the board
MCU_SCL: R201.1, U202.4 (SCL); also elsewhere on the board
MCU_SDA: R202.1, U202.5 (SDA); also elsewhere on the board
unnamed: D201.1 (K), R217.2
unnamed: D202.2 (A), R224.2
unnamed: IC201.9 (A8), R212.2
unnamed: IC201.10 (OE), R213.2, R215.1
unnamed: IC202.10 (OE), R214.2, R216.1
unnamed: J203.1, R210.2
unnamed: J206.8 (DAT1), R219.1
unnamed: J206.9 (DAT2), R218.1
unnamed: R209.2, S201.1, S201.2
unnamed: R211.2, U202.10 (CLK0)
unnamed: C202.2, U202.2 (XA), Y201.3 (OUT/IN)
unnamed: C201.2, U202.3 (XB), Y201.1 (IN/OUT)
OUT_MINUS: J202.16; also elsewhere on the board
OUT_PLUS: J202.15; also elsewhere on the board
OUT_XTAL: J202.9; also elsewhere on the board
P_BIAS: J201.6; also elsewhere on the board
SysCtrl_JTAG_TCK: IC201.1 (A1), J201.3, R203.2, U201.76 (JTAG_TCK); also elsewhere on the board
SysCtrl_JTAG_TDI: IC201.3 (A2), J201.4, R204.2, U201.74 (JTAG_TDI); also elsewhere on the board
SysCtrl_JTAG_TDO: IC201.4 (A3), J201.5, R205.2, U201.73 (JTAG_TDO); also elsewhere on the board
SysCtrl_JTAG_TMS: IC201.5 (A4), J201.7, R206.2, U201.71 (JTAG_TMS); also elsewhere on the board
SysCtrl_JTAG_TRST: IC201.6 (A5), J201.8, R207.2, U201.70 (JTAG_TRST)
SysCtrl_UART_RX: IC201.7 (A6), J201.9, U201.69 (UART_RX); also elsewhere on the board
SysCtrl_UART_TX: IC201.8 (A7), J201.10, U201.68 (UART_TX); also elsewhere on the board
VDD_OUT: J202.13; also elsewhere on the board
VDD_OUT_XTAL: J202.10; also elsewhere on the board
VDD_SUB3: J202.7; also elsewhere on the board
VDD_XTAL: J202.12; also elsewhere on the board
XI: J202.14; also elsewhere on the board
XO: J202.11; also elsewhere on the board

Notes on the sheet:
SysCtrl 3.3V IO
1.8V/3.3V Level shifters
SD card
High resistance needed because of level shifters
SysCtrl
Clock generator
1.8V IO

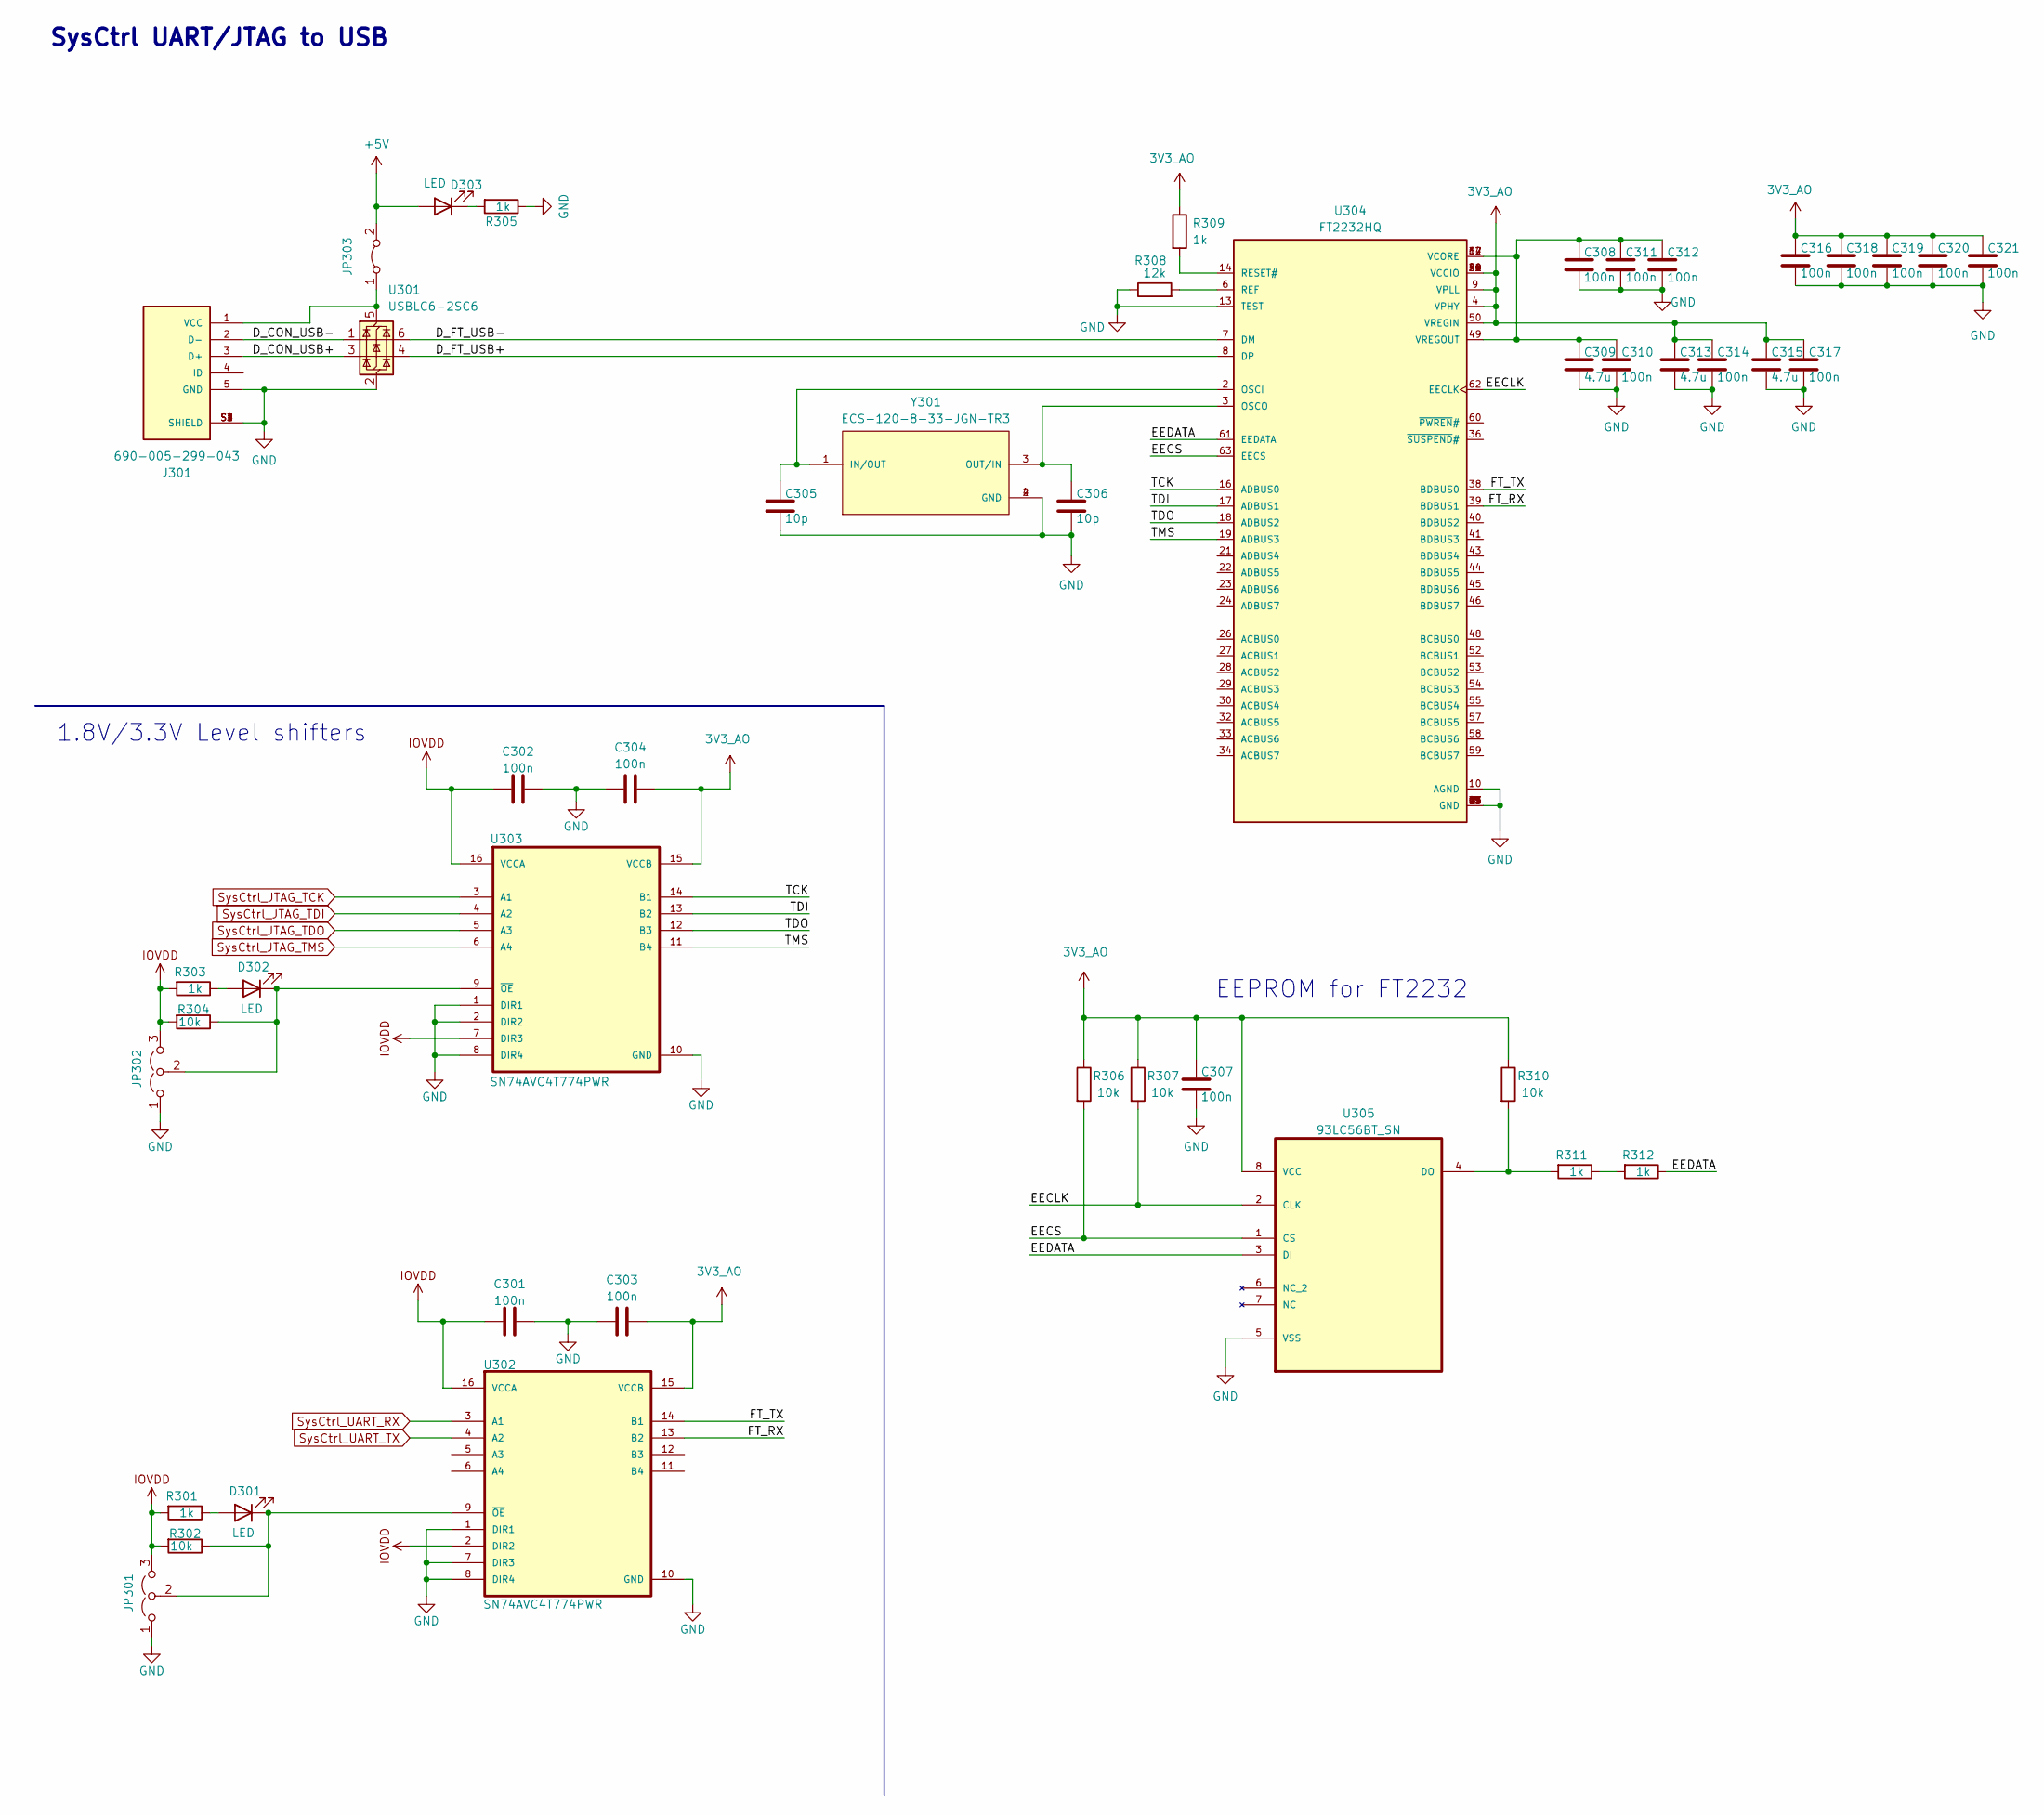
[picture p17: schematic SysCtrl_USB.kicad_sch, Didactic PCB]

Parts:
C301, C302, C303, C304, C307, C308, C310, C311, C312, C314, C316, C317, C318, C319, C320, C321: 100n; C_0603_1608Metric; MANUFACTURER_PART_NUMBER GPC0603104
C305, C306: 10p; C_0603_1608Metric; MANUFACTURER_PART_NUMBER GPC0603100
C309, C313, C315: 4.7u; C_0603_1608Metric; MANUFACTURER_PART_NUMBER GPC0603475-10
D301, D302, D303: LED; LED_0603_1608Metric; MANUFACTURER_PART_NUMBER APHD1608LSURCK
J301: 690-005-299-043; EDAC_690-005-299-043; PARTREV 11
JP301, JP302: Jumper_3_Open; PinHeader_1x03_P2.54mm_Vertical; MANUFACTURER_PART_NUMBER 61300311121
JP303: Jumper_2_Bridged; PinHeader_1x02_P2.54mm_Vertical; MANUFACTURER_PART_NUMBER 61300211121
R301, R303, R305, R309, R311, R312: 1k; R_0603_1608Metric; MANUFACTURER_PART_NUMBER GPR06031K
R302, R304, R306, R307, R310: 10k; R_0603_1608Metric; MANUFACTURER_PART_NUMBER GPR060310K
R308: 12k; R_0603_1608Metric; MANUFACTURER_PART_NUMBER GPR060312K
U301: USBLC6-2SC6; SOT-23-6; MANUFACTURER_PART_NUMBER USBLC6-2SC6
U302, U303: SN74AVC4T774PWR; SOP65P640X120-16N; MANUFACTURER_PART_NUMBER SN74AVC4T774PWR
U304: FT2232HQ; QFN50P900X900X100-65N; MANUFACTURER_PART_NUMBER FT2232HQ
U305: 93LC56BT_SN; SOIC127P600X175-8N; MPN 93LC56BT/SN
Y301: ECS-120-8-33-JGN-TR3; XTAL_ECS-120-8-33-JGN-TR3; MANUFACTURER_PART_NUMBER ECS-120-8-33-JGN-TR3

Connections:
3V3_AO: C303.2, C304.2, C307.1, C313.1, C314.1, C315.1, C316.1, C317.1, C318.1, C319.1, C320.1, C321.1, R306.1, R307.1, R309.1, R310.1, U302.15 (VCCB), U303.15 (VCCB), U304.4 (VPHY), U304.9 (VPLL), U304.20 (VCCIO), U304.31 (VCCIO), U304.42 (VCCIO), U304.50 (VREGIN), U304.56 (VCCIO), U305.8 (VCC); also elsewhere on the board
+5V: D303.2 (A), JP303.2 (B); also elsewhere on the board
/SysCtrl_USB/D_CON_USB+: J301.3 (D+), U301.3 (I/O2)
/SysCtrl_USB/D_CON_USB-: J301.2 (D-), U301.1 (I/O1)
/SysCtrl_USB/D_FT_USB+: U301.4 (I/O2), U304.8 (DP)
/SysCtrl_USB/D_FT_USB-: U301.6 (I/O1), U304.7 (DM)
/SysCtrl_USB/EECLK: R307.2, U304.62 (EECLK), U305.2 (CLK)
/SysCtrl_USB/EECS: R306.2, U304.63 (EECS), U305.1 (CS)
/SysCtrl_USB/EEDATA: R312.1, U304.61 (EEDATA), U305.3 (DI)
/SysCtrl_USB/FT_RX: U302.13 (B2), U304.39 (BDBUS1)
/SysCtrl_USB/FT_TX: U302.14 (B1), U304.38 (BDBUS0)
/SysCtrl_USB/TCK: U303.14 (B1), U304.16 (ADBUS0)
/SysCtrl_USB/TDI: U303.13 (B2), U304.17 (ADBUS1)
/SysCtrl_USB/TDO: U303.12 (B3), U304.18 (ADBUS2)
/SysCtrl_USB/TMS: U303.11 (B4), U304.19 (ADBUS3)
GND: C301.2, C302.2, C303.1, C304.1, C305.2, C306.2, C307.2, C308.2, C309.2, C310.2, C311.2, C312.2, C313.2, C314.2, C315.2, C316.2, C317.2, C318.2, C319.2, C320.2, C321.2, J301.5 (GND), J301.S1 (SHIELD), J301.S2 (SHIELD), J301.S3 (SHIELD), J301.S4 (SHIELD), JP301.1 (A), JP302.1 (A), R305.1, R308.1, U301.2 (GND), U302.1 (DIR1), U302.7 (DIR3), U302.8 (DIR4), U302.10 (GND), U303.1 (DIR1), U303.2 (DIR2), U303.8 (DIR4), U303.10 (GND), U304.1 (GND), U304.5 (GND), U304.10 (AGND), U304.11 (GND), U304.13 (TEST), U304.15 (GND), U304.25 (GND), U304.35 (GND), U304.47 (GND), U304.51 (GND), U304.65 (GND), U305.5 (VSS), Y301.2 (GND), Y301.4 (GND); also elsewhere on the board
IOVDD: C301.1, C302.1, JP301.3 (B), JP302.3 (B), R301.2, R302.2, R303.2, R304.2, U302.2 (DIR2), U302.16 (VCCA), U303.7 (DIR3), U303.16 (VCCA); also elsewhere on the board
unnamed: D301.2 (A), R301.1
unnamed: D301.1 (K), JP301.2 (C), R302.1, U302.9 (~OE)
unnamed: D302.2 (A), R303.1
unnamed: D302.1 (K), JP302.2 (C), R304.1, U303.9 (~OE)
unnamed: D303.1 (K), R305.2
unnamed: J301.1 (VCC), JP303.1 (A), U301.5 (VBUS)
unnamed: R311.1, R312.2
unnamed: C305.1, U304.2 (OSCI), Y301.1 (IN/OUT)
unnamed: C306.1, U304.3 (OSCO), Y301.3 (OUT/IN)
unnamed: R308.2, U304.6 (REF)
unnamed: C308.1, C309.1, C310.1, C311.1, C312.1, U304.12 (VCORE), U304.37 (VCORE), U304.49 (VREGOUT), U304.64 (VCORE)
unnamed: R309.2, U304.14 (~RESET#)
unnamed: R310.2, R311.2, U305.4 (DO)
SysCtrl_JTAG_TCK: U303.3 (A1); also elsewhere on the board
SysCtrl_JTAG_TDI: U303.4 (A2); also elsewhere on the board
SysCtrl_JTAG_TDO: U303.5 (A3); also elsewhere on the board
SysCtrl_JTAG_TMS: U303.6 (A4); also elsewhere on the board
SysCtrl_UART_RX: U302.3 (A1); also elsewhere on the board
SysCtrl_UART_TX: U302.4 (A2); also elsewhere on the board

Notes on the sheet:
SysCtrl UART/JTAG to USB
1.8V/3.3V Level shifters
EEPROM for FT2232

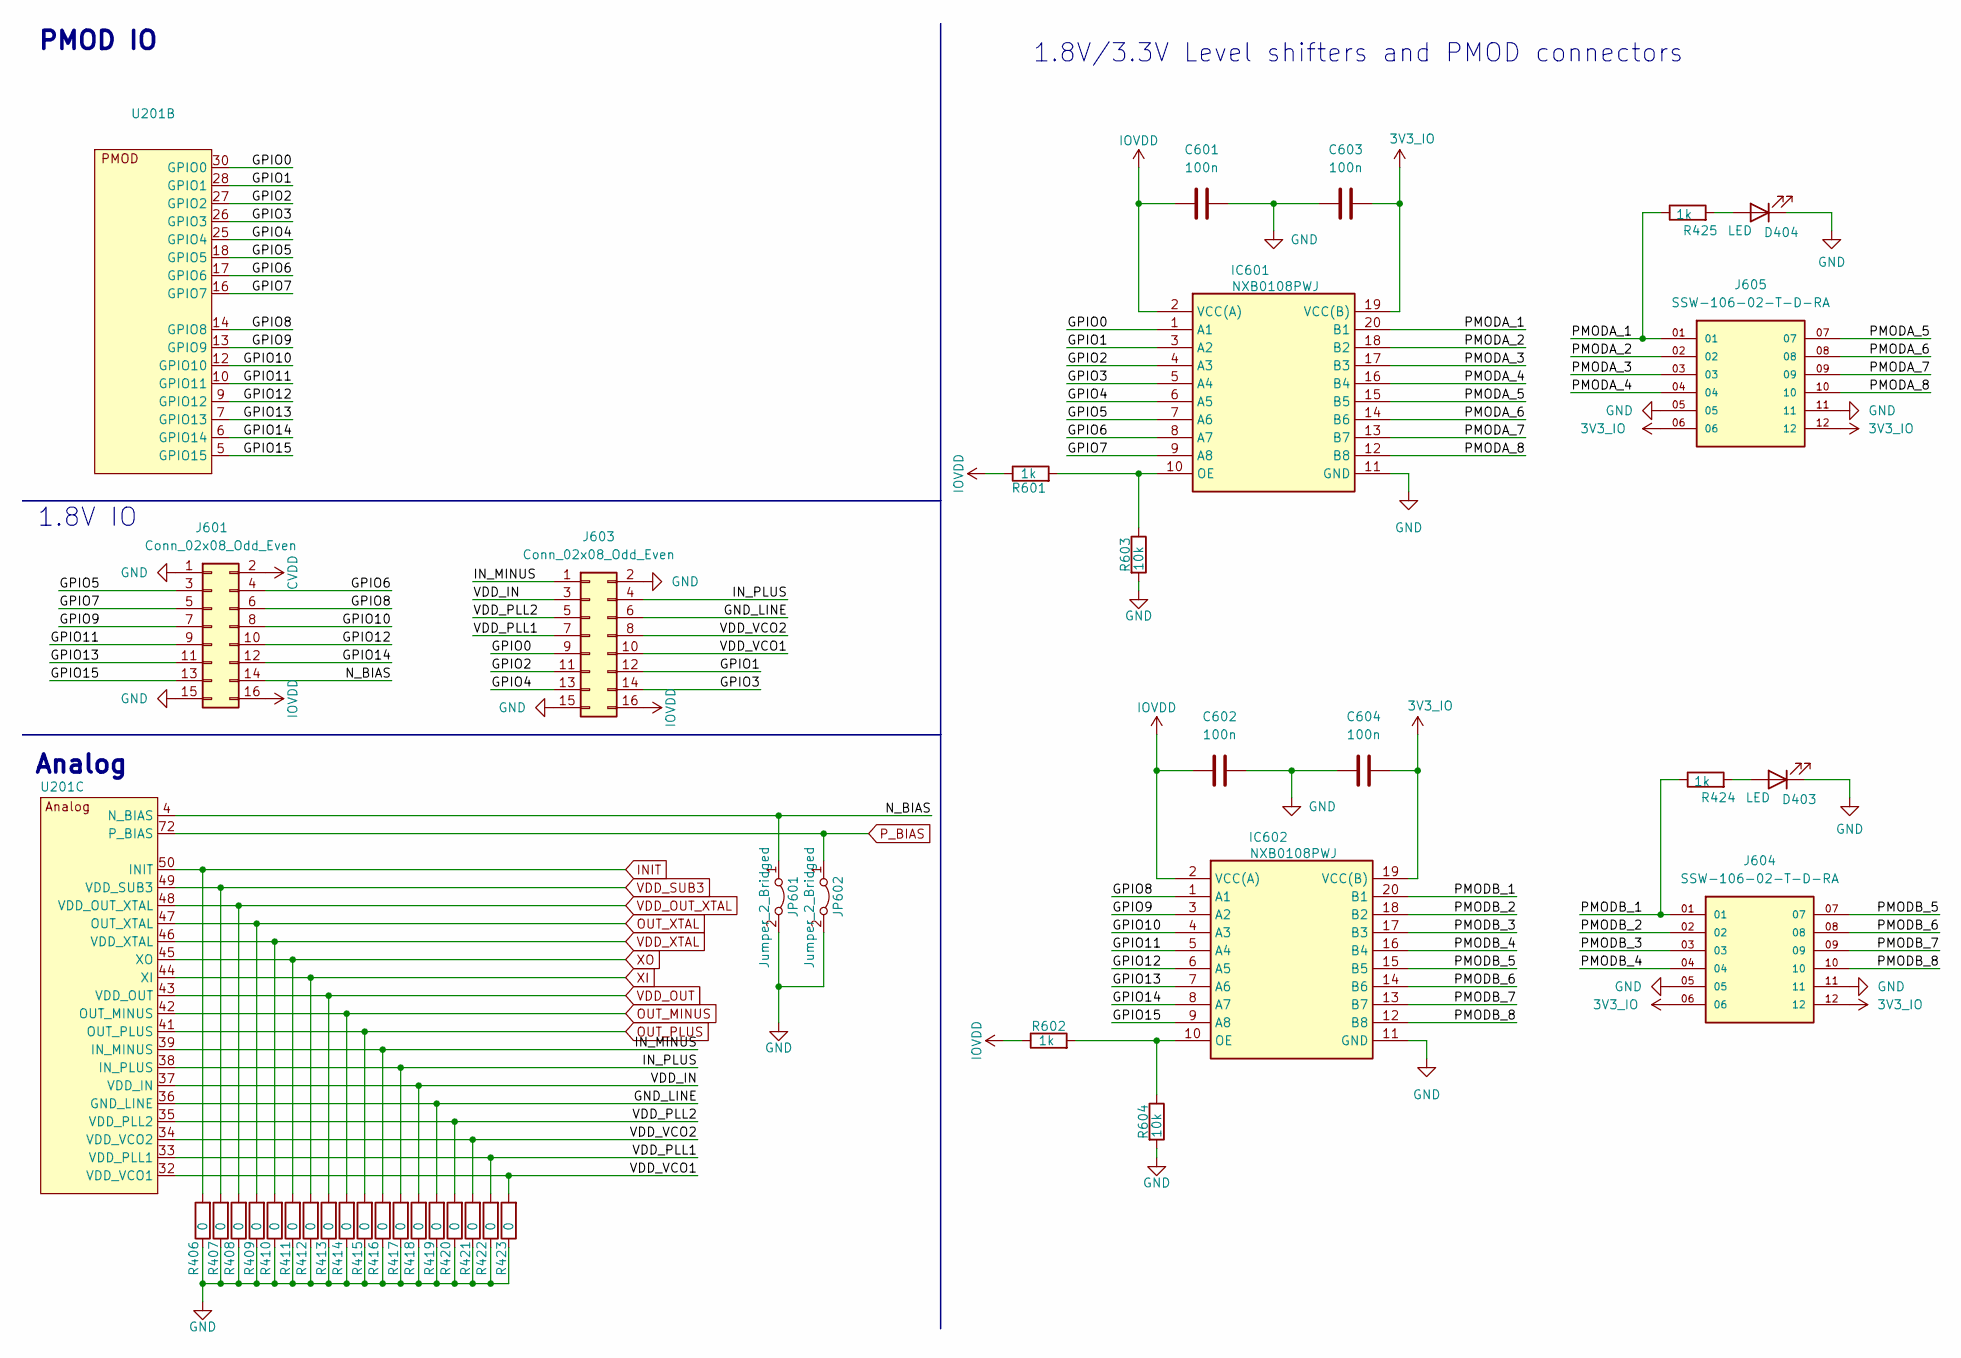
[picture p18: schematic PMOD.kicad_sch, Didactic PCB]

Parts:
C601, C602, C603, C604: 100n; C_0603_1608Metric; MANUFACTURER_PART_NUMBER GPC0603104
D403, D404: LED; LED_0603_1608Metric; MANUFACTURER_PART_NUMBER APHD1608LSURCK
IC601, IC602: NXB0108PWJ; Mouser Part Number 771-NXB0108PWJ
J601, J603: Conn_02x08_Odd_Even; PinHeader_2x08_P2.54mm_Vertical; MANUFACTURER_PART_NUMBER 77313-101-16LF
J604, J605: SSW-106-02-T-D-RA; SAMTEC_SSW-106-02-T-D-RA; PARTREV R
JP601, JP602: Jumper_2_Bridged; PinHeader_1x02_P2.54mm_Vertical; MANUFACTURER_PART_NUMBER 61300211121
R406, R407, R408, R409, R410, R411, R412, R413, R414, R415, R416, R417, R418, R419, R420, R421, R422, R423: 0; R_0603_1608Metric; MANUFACTURER_PART_NUMBER GPR06030R
R424, R425, R601, R602: 1k; R_0603_1608Metric; MANUFACTURER_PART_NUMBER GPR06031K
R603, R604: 10k; R_0603_1608Metric; MANUFACTURER_PART_NUMBER GPR060310K
U201: Didactic_QFN-80_EP_12x12_Pitch0.5mm

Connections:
3V3_IO: C603.2, C604.2, IC601.19 (VCC(B)), IC602.19 (VCC(B)), J604.06, J604.12, J605.06, J605.12; also elsewhere on the board
/PMOD/GND_LINE: J603.6, R419.2, U201.36 (GND_LINE)
/PMOD/GPIO0: IC601.1 (A1), J603.9, U201.30 (GPIO0)
/PMOD/GPIO1: IC601.3 (A2), J603.12, U201.28 (GPIO1)
/PMOD/GPIO2: IC601.4 (A3), J603.11, U201.27 (GPIO2)
/PMOD/GPIO3: IC601.5 (A4), J603.14, U201.26 (GPIO3)
/PMOD/GPIO4: IC601.6 (A5), J603.13, U201.25 (GPIO4)
/PMOD/GPIO5: IC601.7 (A6), J601.3, U201.18 (GPIO5)
/PMOD/GPIO6: IC601.8 (A7), J601.4, U201.17 (GPIO6)
/PMOD/GPIO7: IC601.9 (A8), J601.5, U201.16 (GPIO7)
/PMOD/GPIO8: IC602.1 (A1), J601.6, U201.14 (GPIO8)
/PMOD/GPIO9: IC602.3 (A2), J601.7, U201.13 (GPIO9)
/PMOD/GPIO10: IC602.4 (A3), J601.8, U201.12 (GPIO10)
/PMOD/GPIO11: IC602.5 (A4), J601.9, U201.10 (GPIO11)
/PMOD/GPIO12: IC602.6 (A5), J601.10, U201.9 (GPIO12)
/PMOD/GPIO13: IC602.7 (A6), J601.11, U201.7 (GPIO13)
/PMOD/GPIO14: IC602.8 (A7), J601.12, U201.6 (GPIO14)
/PMOD/GPIO15: IC602.9 (A8), J601.13, U201.5 (GPIO15)
/PMOD/IN_MINUS: J603.1, R416.2, U201.39 (IN_MINUS)
/PMOD/IN_PLUS: J603.4, R417.2, U201.38 (IN_PLUS)
/PMOD/N_BIAS: J601.14, JP601.1 (A), U201.4 (N_BIAS)
/PMOD/PMODA_1: IC601.20 (B1), J605.01, R425.1
/PMOD/PMODA_2: IC601.18 (B2), J605.02
/PMOD/PMODA_3: IC601.17 (B3), J605.03
/PMOD/PMODA_4: IC601.16 (B4), J605.04
/PMOD/PMODA_5: IC601.15 (B5), J605.07
/PMOD/PMODA_6: IC601.14 (B6), J605.08
/PMOD/PMODA_7: IC601.13 (B7), J605.09
/PMOD/PMODA_8: IC601.12 (B8), J605.10
/PMOD/PMODB_1: IC602.20 (B1), J604.01, R424.1
/PMOD/PMODB_2: IC602.18 (B2), J604.02
/PMOD/PMODB_3: IC602.17 (B3), J604.03
/PMOD/PMODB_4: IC602.16 (B4), J604.04
/PMOD/PMODB_5: IC602.15 (B5), J604.07
/PMOD/PMODB_6: IC602.14 (B6), J604.08
/PMOD/PMODB_7: IC602.13 (B7), J604.09
/PMOD/PMODB_8: IC602.12 (B8), J604.10
/PMOD/VDD_IN: J603.3, R418.2, U201.37 (VDD_IN)
/PMOD/VDD_PLL1: J603.7, R422.2, U201.33 (VDD_PLL1)
/PMOD/VDD_PLL2: J603.5, R420.2, U201.35 (VDD_PLL2)
/PMOD/VDD_VCO1: J603.10, R423.2, U201.32 (VDD_VCO1)
/PMOD/VDD_VCO2: J603.8, R421.2, U201.34 (VDD_VCO2)
CVDD: J601.2; also elsewhere on the board
GND: C601.2, C602.2, C603.1, C604.1, D403.1 (K), D404.1 (K), IC601.11 (GND), IC602.11 (GND), J601.1, J601.15, J603.2, J603.15, J604.05, J604.11, J605.05, J605.11, JP601.2 (B), JP602.2 (B), R406.1, R407.1, R408.1, R409.1, R410.1, R411.1, R412.1, R413.1, R414.1, R415.1, R416.1, R417.1, R418.1, R419.1, R420.1, R421.1, R422.1, R423.1, R603.2, R604.2; also elsewhere on the board
INIT: R406.2, U201.50 (INIT); also elsewhere on the board
IOVDD: C601.1, C602.1, IC601.2 (VCC(A)), IC602.2 (VCC(A)), J601.16, J603.16, R601.1, R602.1; also elsewhere on the board
unnamed: D403.2 (A), R424.2
unnamed: D404.2 (A), R425.2
unnamed: IC601.10 (OE), R601.2, R603.1
unnamed: IC602.10 (OE), R602.2, R604.1
OUT_MINUS: R414.2, U201.42 (OUT_MINUS); also elsewhere on the board
OUT_PLUS: R415.2, U201.41 (OUT_PLUS); also elsewhere on the board
OUT_XTAL: R409.2, U201.47 (OUT_XTAL); also elsewhere on the board
P_BIAS: JP602.1 (A), U201.72 (P_BIAS); also elsewhere on the board
VDD_OUT: R413.2, U201.43 (VDD_OUT); also elsewhere on the board
VDD_OUT_XTAL: R408.2, U201.48 (VDD_OUT_XTAL); also elsewhere on the board
VDD_SUB3: R407.2, U201.49 (VDD_SUB3); also elsewhere on the board
VDD_XTAL: R410.2, U201.46 (VDD_XTAL); also elsewhere on the board
XI: R412.2, U201.44 (XI); also elsewhere on the board
XO: R411.2, U201.45 (XO); also elsewhere on the board

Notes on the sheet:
PMOD IO
Analog
1.8V IO
1.8V/3.3V Level shifters and PMOD connectors

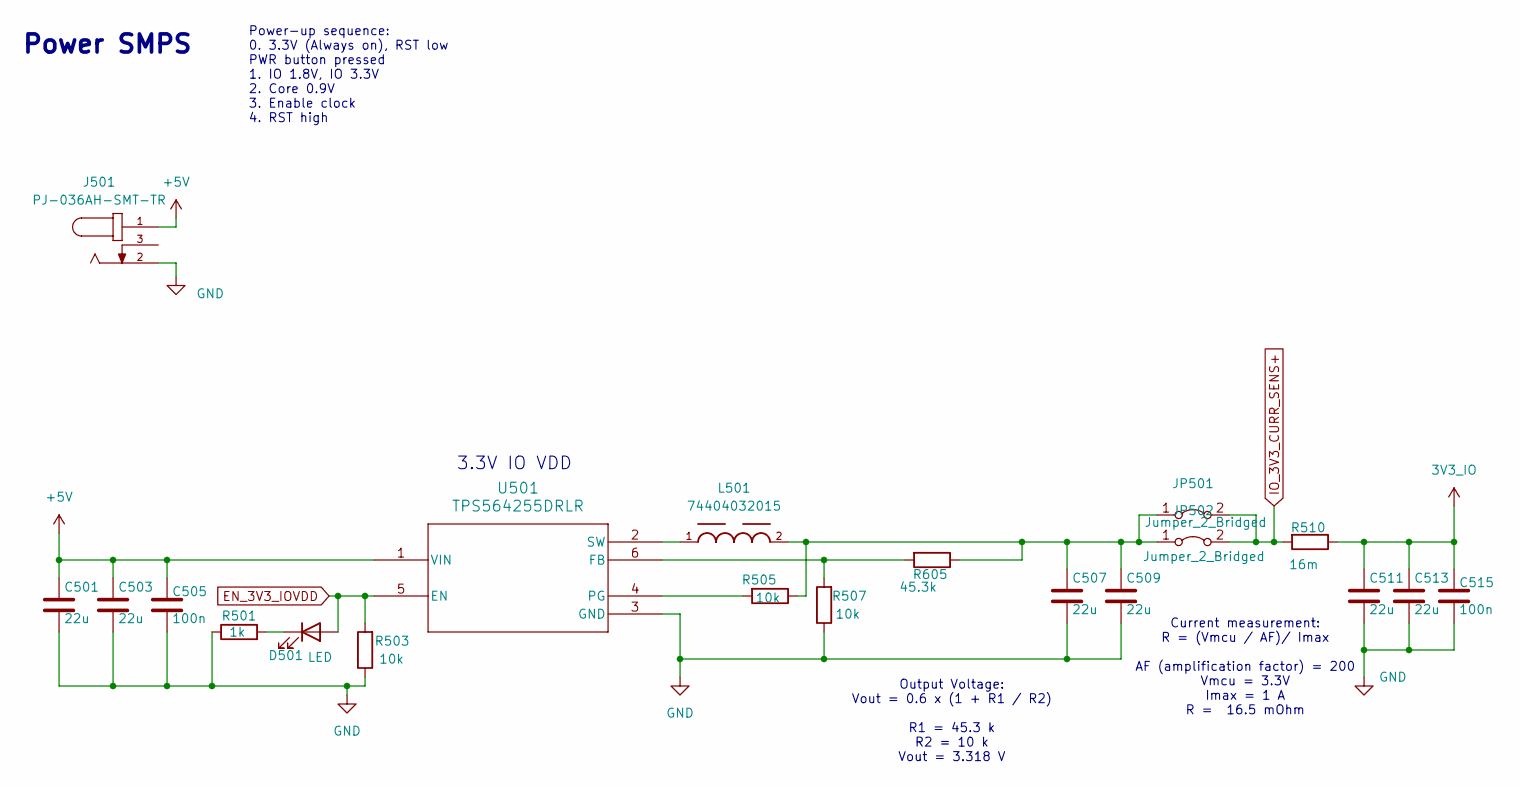
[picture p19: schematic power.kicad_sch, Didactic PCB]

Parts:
C501, C503, C507, C509, C511, C513: 22u; C_1206_3216Metric; MANUFACTURER_PART_NUMBER CL31A226KAHNNNE
C505, C515: 100n; C_0603_1608Metric; MANUFACTURER_PART_NUMBER GPC0603104
D501: LED; LED_0603_1608Metric; MANUFACTURER_PART_NUMBER APHD1608LSURCK
J501: PJ-036AH-SMT-TR; CUI_PJ-036AH-SMT-TR; MANUFACTURER_PART_NUMBER PJ-036AH-SMT-TR; DIGI-KEY_PART_NUMBER CP-036AHPJCT-ND
JP501, JP502: Jumper_2_Bridged; PinHeader_1x02_P2.54mm_Vertical; MANUFACTURER_PART_NUMBER 61300211121
L501: 74404032015; WE-LQS_3015; MANUFACTURER_PART_NUMBER 74404032015
R501: 1k; R_0603_1608Metric; MANUFACTURER_PART_NUMBER GPR06031K
R503, R505, R507: 10k; R_0603_1608Metric; MANUFACTURER_PART_NUMBER GPR060310K
R510: 16m; R_1206_3216Metric; MANUFACTURER_PART_NUMBER ERJ-8CWFR016V
R605: 45.3k; R_0603_1608Metric; MANUFACTURER_PART_NUMBER CPF0603F45K3C1
U501: TPS564255DRLR; TPS564242DRLR_TEX; MANUFACTURER_PART_NUMBER TPS564255DRLR

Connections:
3V3_IO: C511.2, C513.2, C515.1, R510.1; also elsewhere on the board
+5V: C501.2, C503.2, C505.1, J501.1, U501.1 (VIN); also elsewhere on the board
EN_3V3_IOVDD: D501.2 (A), R503.2, U501.5 (EN); also elsewhere on the board
GND: C501.1, C503.1, C505.2, C507.1, C509.1, C511.1, C513.1, C515.2, J501.2, R501.1, R503.1, R507.1, U501.3 (GND); also elsewhere on the board
IO_3V3_CURR_SENS+: JP501.2 (B), JP502.2 (B), R510.2; also elsewhere on the board
unnamed: D501.1 (K), R501.2
unnamed: C507.2, C509.2, JP501.1 (A), JP502.1 (A), L501.2, R505.1, R605.1
unnamed: R507.2, R605.2, U501.6 (FB)
unnamed: R505.2, U501.4 (PG)
unnamed: L501.1, U501.2 (SW)

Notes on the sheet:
Current measurement: R = (Vmcu / AF)/ Imax AF (amplification factor) = 200 Vmcu = 3.3V Imax = 1 A R = 16.5 mOhm
Power SMPS
Output Voltage: Vout = 0.6 x (1 + R1 / R2) R1 = 45.3 k R2 = 10 k Vout = 3.318 V
Power-up sequence: 0. 3.3V (Always on), RST low PWR button pressed 1. IO 1.8V, IO 3.3V 2. Core 0.9V 3. Enable clock 4. RST high
3.3V IO VDD

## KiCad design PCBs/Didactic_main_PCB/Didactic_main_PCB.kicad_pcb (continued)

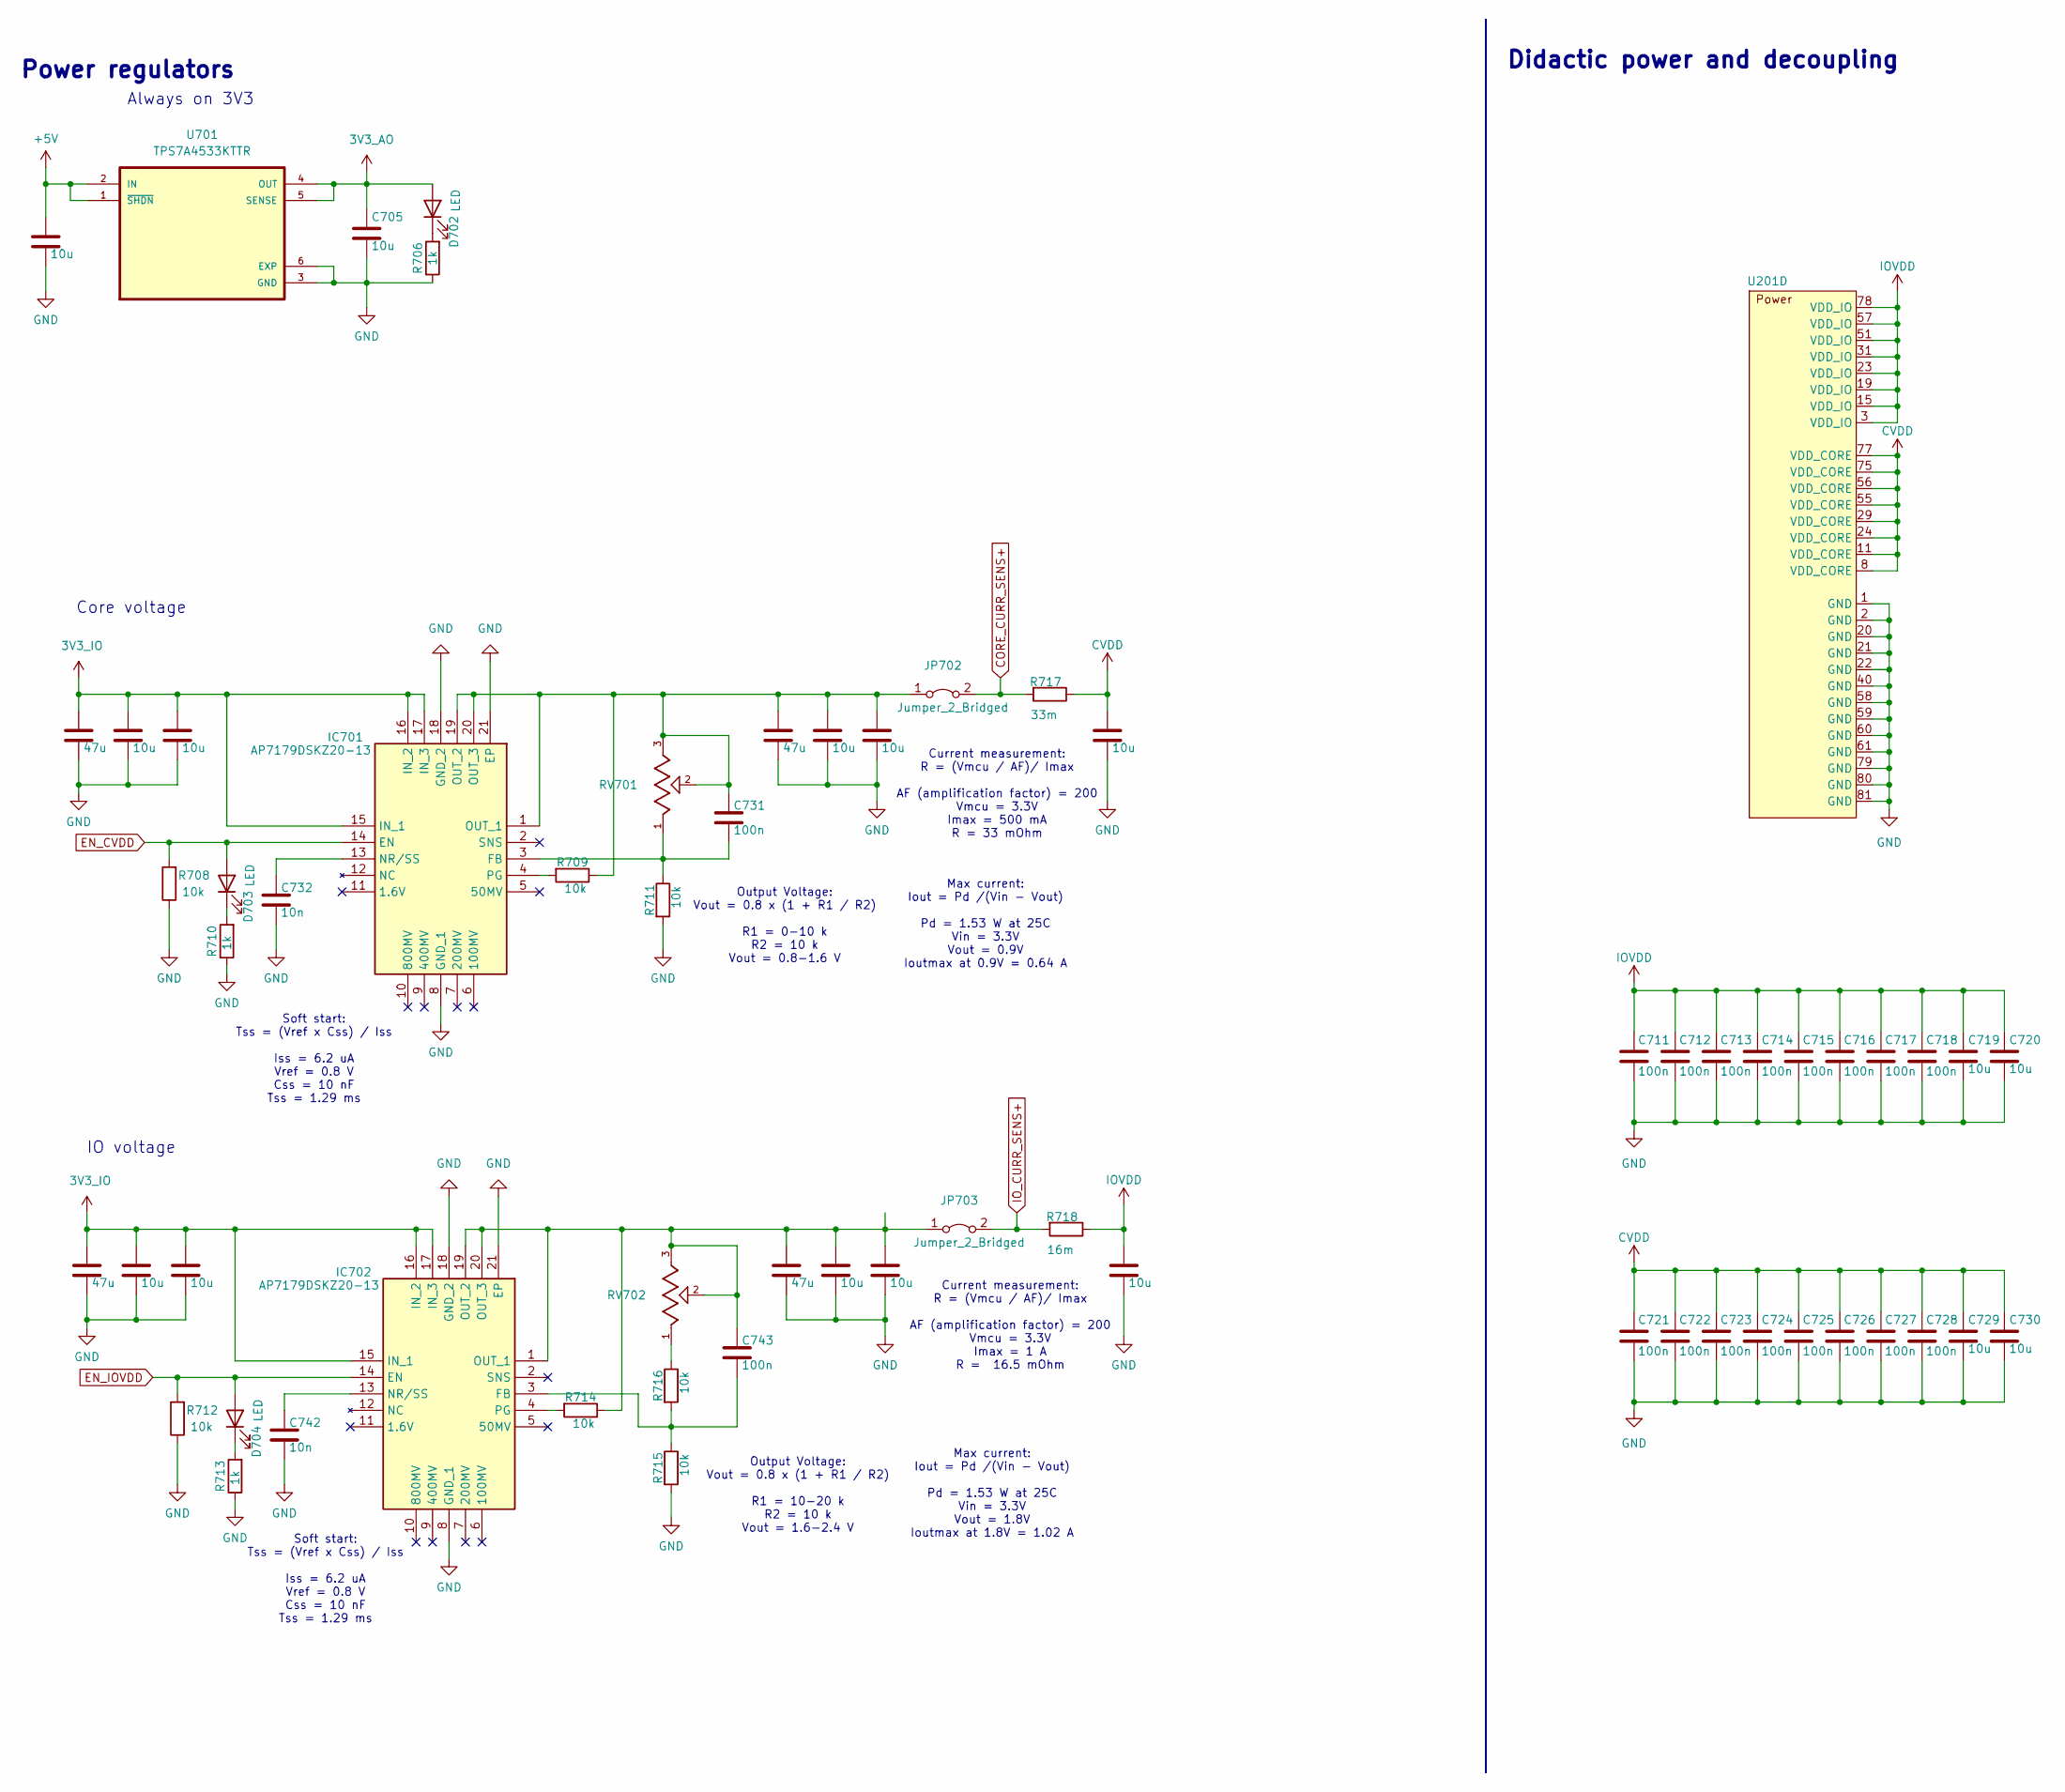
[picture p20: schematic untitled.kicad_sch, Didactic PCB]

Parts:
C703, C705, C719, C720, C729, C730, C734, C735, C737, C738, C740, C741, C745, C746, C747, C748: 10u; C_0805_2012Metric; MANUFACTURER_PART_NUMBER GPC0805106-25
C711, C712, C713, C714, C715, C716, C717, C718, C721, C722, C723, C724, C725, C726, C727, C728, C731, C743: 100n; C_0603_1608Metric; MANUFACTURER_PART_NUMBER GPC0603104
C732, C742: 10n; C_0603_1608Metric; MANUFACTURER_PART_NUMBER GPC0603103
C733, C736, C739, C744: 47u; C_0805_2012Metric; MANUFACTURER_PART_NUMBER GPC0805476-6.3
D702, D703, D704: LED; LED_0603_1608Metric; MANUFACTURER_PART_NUMBER APHD1608LSURCK
IC701, IC702: AP7179DSKZ20-13; QFN50P350X350X80-21N-D; Manufacturer_Part_Number AP7179DSKZ20-13
JP702, JP703: Jumper_2_Bridged; PinHeader_1x02_P2.54mm_Vertical; MANUFACTURER_PART_NUMBER 61300211121
R706, R710, R713: 1k; R_0603_1608Metric; MANUFACTURER_PART_NUMBER GPR06031K
R708, R709, R711, R712, R714, R715, R716: 10k; R_0603_1608Metric; MANUFACTURER_PART_NUMBER GPR060310K
R717: 33m; R_1206_3216Metric; MANUFACTURER_PART_NUMBER ERJ-8CWFR033V
R718: 16m; R_1206_3216Metric; MANUFACTURER_PART_NUMBER ERJ-8CWFR016V
RV701, RV702: PV36W103C01B00; TRIM_PV36W103C01B00; PARTREV N/A
U201: Didactic_QFN-80_EP_12x12_Pitch0.5mm
U701: TPS7A4533KTTR; VREG_TPS79625KTTR; MANUFACTURER_PART_NUMBER TPS7A4533KTTR

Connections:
3V3_AO: C705.2, D702.2 (A), U701.4 (OUT), U701.5 (SENSE); also elsewhere on the board
3V3_IO: C736.2, C737.2, C738.2, C739.2, C740.2, C741.2, IC701.15 (IN_1), IC701.16 (IN_2), IC701.17 (IN_3), IC702.15 (IN_1), IC702.16 (IN_2), IC702.17 (IN_3); also elsewhere on the board
+5V: C703.2, U701.1 (~SHDN), U701.2 (IN); also elsewhere on the board
CORE_CURR_SENS+: JP702.2 (B), R717.2; also elsewhere on the board
CVDD: C721.2, C722.2, C723.2, C724.2, C725.2, C726.2, C727.2, C728.2, C729.2, C730.2, C747.2, R717.1, U201.8 (VDD_CORE), U201.11 (VDD_CORE), U201.24 (VDD_CORE), U201.29 (VDD_CORE), U201.55 (VDD_CORE), U201.56 (VDD_CORE), U201.75 (VDD_CORE), U201.77 (VDD_CORE); also elsewhere on the board
EN_CVDD: D703.2 (A), IC701.14 (EN), R708.2; also elsewhere on the board
EN_IOVDD: D704.2 (A), IC702.14 (EN), R712.2; also elsewhere on the board
GND: C703.1, C705.1, C711.1, C712.1, C713.1, C714.1, C715.1, C716.1, C717.1, C718.1, C719.1, C720.1, C721.1, C722.1, C723.1, C724.1, C725.1, C726.1, C727.1, C728.1, C729.1, C730.1, C732.2, C733.1, C734.1, C735.1, C736.1, C737.1, C738.1, C739.1, C740.1, C741.1, C742.2, C744.1, C745.1, C746.1, C747.1, C748.1, IC701.8 (GND_1), IC701.18 (GND_2), IC701.21 (EP), IC702.8 (GND_1), IC702.18 (GND_2), IC702.21 (EP), R706.1, R708.1, R710.1, R711.2, R712.1, R713.1, R715.2, U201.1 (GND), U201.2 (GND), U201.20 (GND), U201.21 (GND), U201.22 (GND), U201.40 (GND), U201.58 (GND), U201.59 (GND), U201.60 (GND), U201.61 (GND), U201.79 (GND), U201.80 (GND), U201.81 (GND), U701.3 (GND), U701.6 (EXP); also elsewhere on the board
IOVDD: C711.2, C712.2, C713.2, C714.2, C715.2, C716.2, C717.2, C718.2, C719.2, C720.2, C748.2, R718.1, U201.3 (VDD_IO), U201.15 (VDD_IO), U201.19 (VDD_IO), U201.23 (VDD_IO), U201.31 (VDD_IO), U201.51 (VDD_IO), U201.57 (VDD_IO), U201.78 (VDD_IO); also elsewhere on the board
IO_CURR_SENS+: JP703.2 (B), R718.2; also elsewhere on the board
unnamed: D702.1 (K), R706.2
unnamed: D703.1 (K), R710.2
unnamed: D704.1 (K), R713.2
unnamed: C731.2, IC701.3 (FB), R711.1, RV701.1
unnamed: C732.1, IC701.13 (NR/SS)
unnamed: C731.1, C733.2, C734.2, C735.2, IC701.1 (OUT_1), IC701.19 (OUT_2), IC701.20 (OUT_3), JP702.1 (A), R709.1, RV701.2, RV701.3
unnamed: IC701.4 (PG), R709.2
unnamed: C743.2, IC702.3 (FB), R715.1, R716.2
unnamed: C742.1, IC702.13 (NR/SS)
unnamed: C743.1, C744.2, C745.2, C746.2, IC702.1 (OUT_1), IC702.19 (OUT_2), IC702.20 (OUT_3), JP703.1 (A), R714.1, RV702.2, RV702.3
unnamed: IC702.4 (PG), R714.2
unnamed: R716.1, RV702.1

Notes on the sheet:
Current measurement: R = (Vmcu / AF)/ Imax AF (amplification factor) = 200 Vmcu = 3.3V Imax = 1 A R = 16.5 mOhm
IO voltage
Soft start: Tss = (Vref x Css) / Iss Iss = 6.2 uA Vref = 0.8 V Css = 10 nF Tss = 1.29 ms
Max current: Iout = Pd /(Vin - Vout) Pd = 1.53 W at 25C Vin = 3.3V Vout = 0.9V Ioutmax at 0.9V = 0.64 A
Output Voltage: Vout = 0.8 x (1 + R1 / R2) R1 = 10-20 k R2 = 10 k Vout = 1.6-2.4 V
Always on 3V3
Core voltage
Power regulators
Didactic power and decoupling
Max current: Iout = Pd /(Vin - Vout) Pd = 1.53 W at 25C Vin = 3.3V Vout = 1.8V Ioutmax at 1.8V = 1.02 A
Current measurement: R = (Vmcu / AF)/ Imax AF (amplification factor) = 200 Vmcu = 3.3V Imax = 500 mA R = 33 mOhm
Output Voltage: Vout = 0.8 x (1 + R1 / R2) R1 = 0-10 k R2 = 10 k Vout = 0.8-1.6 V

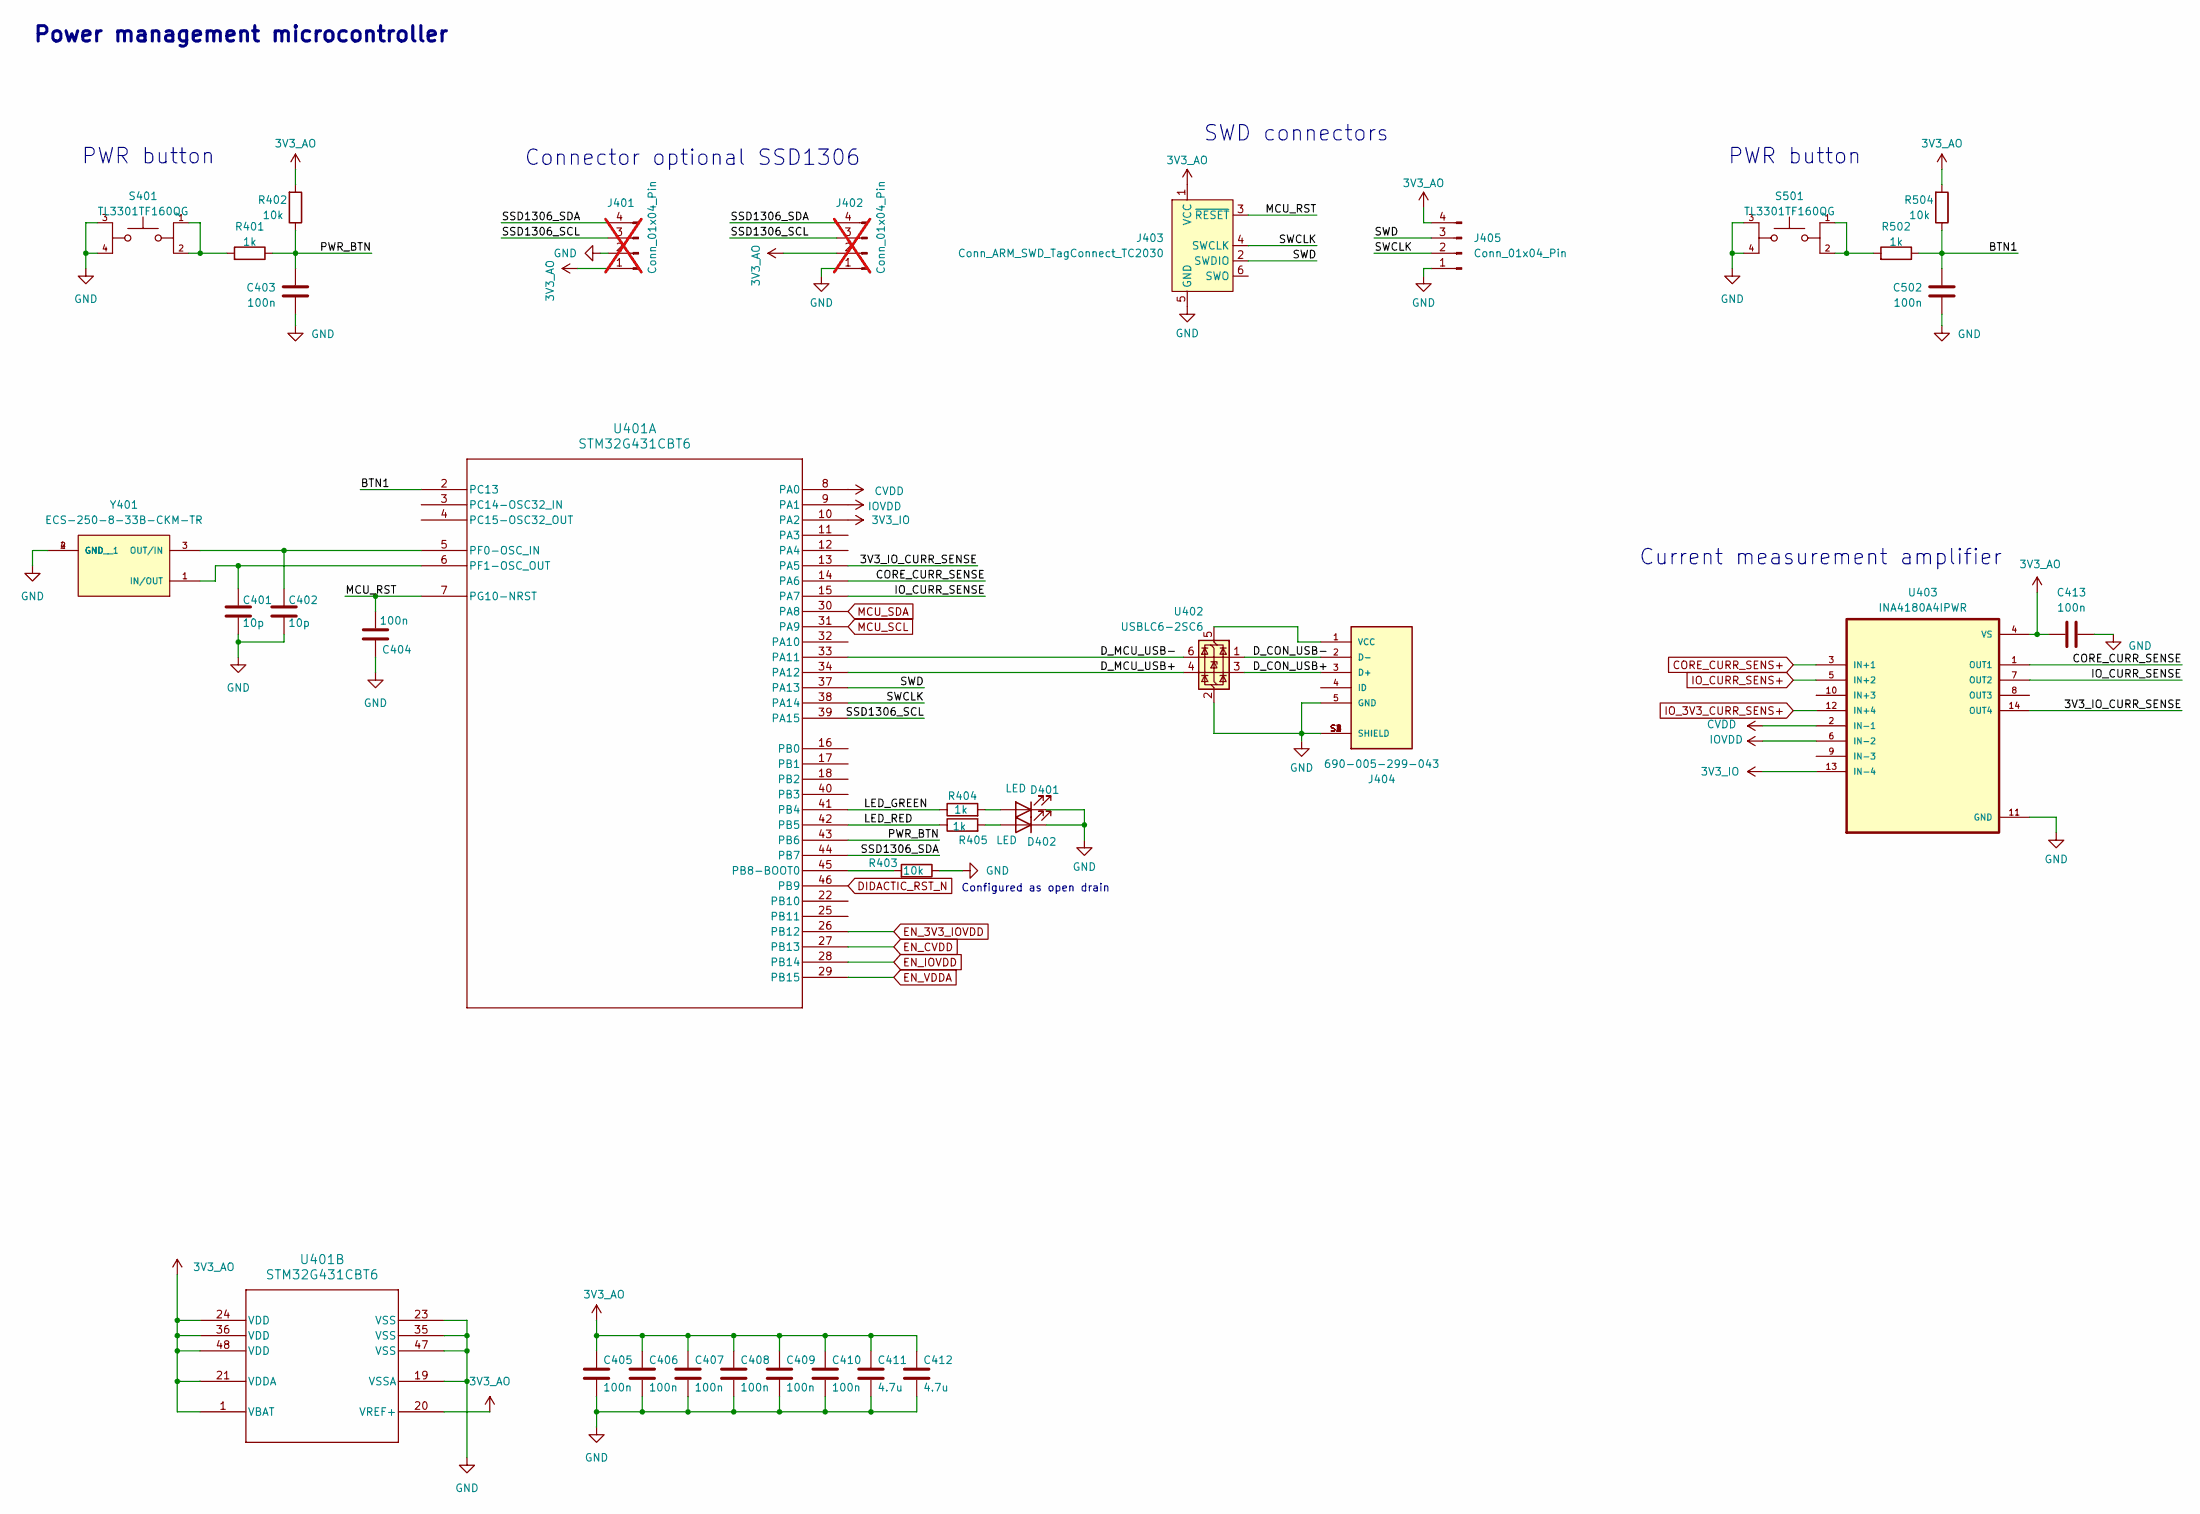
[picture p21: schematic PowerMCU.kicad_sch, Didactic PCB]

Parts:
C401, C402: 10p; C_0603_1608Metric; MANUFACTURER_PART_NUMBER GPC0603100
C403, C404, C405, C406, C407, C408, C409, C410, C413, C502: 100n; C_0603_1608Metric; MANUFACTURER_PART_NUMBER GPC0603104
C411, C412: 4.7u; C_0603_1608Metric; MANUFACTURER_PART_NUMBER GPC0603475-10
D401: LED; LED_0603_1608Metric; MANUFACTURER_PART_NUMBER APHD1608LCGCK
D402: LED; LED_0603_1608Metric; MANUFACTURER_PART_NUMBER APHD1608LSURCK
J401, J402: Conn_01x04_Pin; PinHeader_1x04_P2.54mm_Vertical; MANUFACTURER_PART_NUMBER 77311-424-04LF; not fitted
J403: Conn_ARM_SWD_TagConnect_TC2030; Tag-Connect_TC2030-IDC-FP_2x03_P1.27mm_Vertical
J404: 690-005-299-043; EDAC_690-005-299-043; PARTREV 11
J405: Conn_01x04_Pin; PinHeader_1x04_P2.54mm_Vertical; MANUFACTURER_PART_NUMBER 77311-424-04LF
R401, R404, R405, R502: 1k; R_0603_1608Metric; MANUFACTURER_PART_NUMBER GPR06031K
R402, R403, R504: 10k; R_0603_1608Metric; MANUFACTURER_PART_NUMBER GPR060310K
S401, S501: TL3301TF160QG; SW_TL3301TF160QG; PARTREV E
U401: STM32G431CBT6; LQFP48-7x7mm; MANUFACTURER_PART_NUMBER STM32G431CBT6
U402: USBLC6-2SC6; SOT-23-6; MANUFACTURER_PART_NUMBER USBLC6-2SC6
U403: INA4180A4IPWR; SOP65P640X120-14N; MANUFACTURER_PART_NUMBER INA4180A4IPWR
Y401: ECS-250-8-33B-CKM-TR; XTAL_ECS-250-8-33B-CKM-TR; MANUFACTURER_PART_NUMBER ECS-250-8-33B-CKM-TR

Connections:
3V3_AO: C405.2, C406.2, C407.2, C408.2, C409.2, C410.2, C411.2, C412.2, C413.1, J401.1, J402.2, J403.1 (VCC), J405.4, R402.2, R504.2, U401.1 (VBAT), U401.20 (VREF+), U401.21 (VDDA), U401.24 (VDD), U401.36 (VDD), U401.48 (VDD), U403.4 (VS); also elsewhere on the board
3V3_IO: U401.10 (PA2), U403.13 (IN-4); also elsewhere on the board
/PowerMCU/3V3_IO_CURR_SENSE: U401.13 (PA5), U403.14 (OUT4)
/PowerMCU/BTN1: C502.1, R502.1, R504.1, U401.2 (PC13)
/PowerMCU/CORE_CURR_SENSE: U401.14 (PA6), U403.1 (OUT1)
/PowerMCU/D_CON_USB+: J404.3 (D+), U402.3 (I/O2)
/PowerMCU/D_CON_USB-: J404.2 (D-), U402.1 (I/O1)
/PowerMCU/D_MCU_USB+: U401.34 (PA12), U402.4 (I/O2)
/PowerMCU/D_MCU_USB-: U401.33 (PA11), U402.6 (I/O1)
/PowerMCU/IO_CURR_SENSE: U401.15 (PA7), U403.7 (OUT2)
/PowerMCU/LED_GREEN: R404.1, U401.41 (PB4)
/PowerMCU/LED_RED: R405.1, U401.42 (PB5)
/PowerMCU/MCU_RST: C404.2, J403.3 (~RESET), U401.7 (PG10-NRST)
/PowerMCU/PWR_BTN: C403.1, R401.1, R402.1, U401.43 (PB6)
/PowerMCU/SSD1306_SCL: J401.3, J402.3, U401.39 (PA15)
/PowerMCU/SSD1306_SDA: J401.4, J402.4, U401.44 (PB7)
/PowerMCU/SWCLK: J403.4 (SWCLK), J405.2, U401.38 (PA14)
/PowerMCU/SWD: J403.2 (SWDIO), J405.3, U401.37 (PA13)
CORE_CURR_SENS+: U403.3 (IN+1); also elsewhere on the board
CVDD: U401.8 (PA0), U403.2 (IN-1); also elsewhere on the board
DIDACTIC_RST_N: U401.46 (PB9); also elsewhere on the board
EN_3V3_IOVDD: U401.26 (PB12); also elsewhere on the board
EN_CVDD: U401.27 (PB13); also elsewhere on the board
EN_IOVDD: U401.28 (PB14); also elsewhere on the board
EN_VDDA: U401.29 (PB15)
GND: C401.2, C402.2, C403.2, C404.1, C405.1, C406.1, C407.1, C408.1, C409.1, C410.1, C411.1, C412.1, C413.2, C502.2, D401.1 (K), D402.1 (K), J401.2, J402.1, J403.5 (GND), J404.5 (GND), J404.S1 (SHIELD), J404.S2 (SHIELD), J404.S3 (SHIELD), J404.S4 (SHIELD), J405.1, R403.1, S401.3, S401.4, S501.3, S501.4, U401.19 (VSSA), U401.23 (VSS), U401.35 (VSS), U401.47 (VSS), U402.2 (GND), U403.11 (GND), Y401.2 (GND), Y401.4 (GND__1); also elsewhere on the board
IOVDD: U401.9 (PA1), U403.6 (IN-2); also elsewhere on the board
IO_3V3_CURR_SENS+: U403.12 (IN+4); also elsewhere on the board
IO_CURR_SENS+: U403.5 (IN+2); also elsewhere on the board
MCU_SCL: U401.31 (PA9); also elsewhere on the board
MCU_SDA: U401.30 (PA8); also elsewhere on the board
unnamed: D401.2 (A), R404.2
unnamed: D402.2 (A), R405.2
unnamed: J404.1 (VCC), U402.5 (VBUS)
unnamed: R401.2, S401.1, S401.2
unnamed: R502.2, S501.1, S501.2
unnamed: R403.2, U401.45 (PB8-BOOT0)
unnamed: C402.1, U401.5 (PF0-OSC_IN), Y401.3 (OUT/IN)
unnamed: C401.1, U401.6 (PF1-OSC_OUT), Y401.1 (IN/OUT)

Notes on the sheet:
PWR button
Power management microcontroller
Connector optional SSD1306
Configured as open drain
SWD connectors
Current measurement amplifier

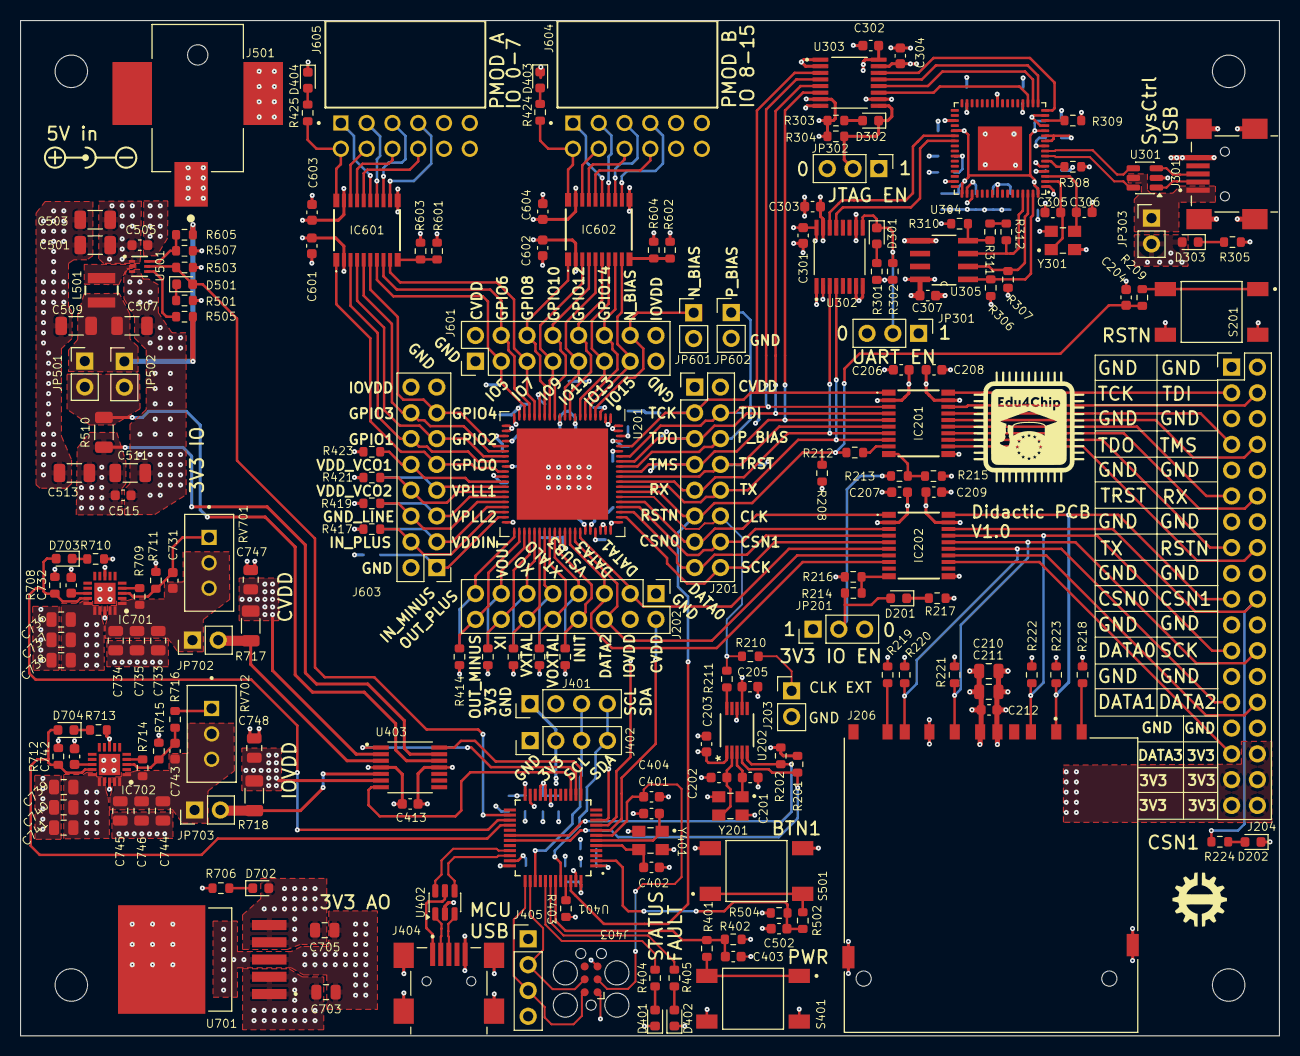
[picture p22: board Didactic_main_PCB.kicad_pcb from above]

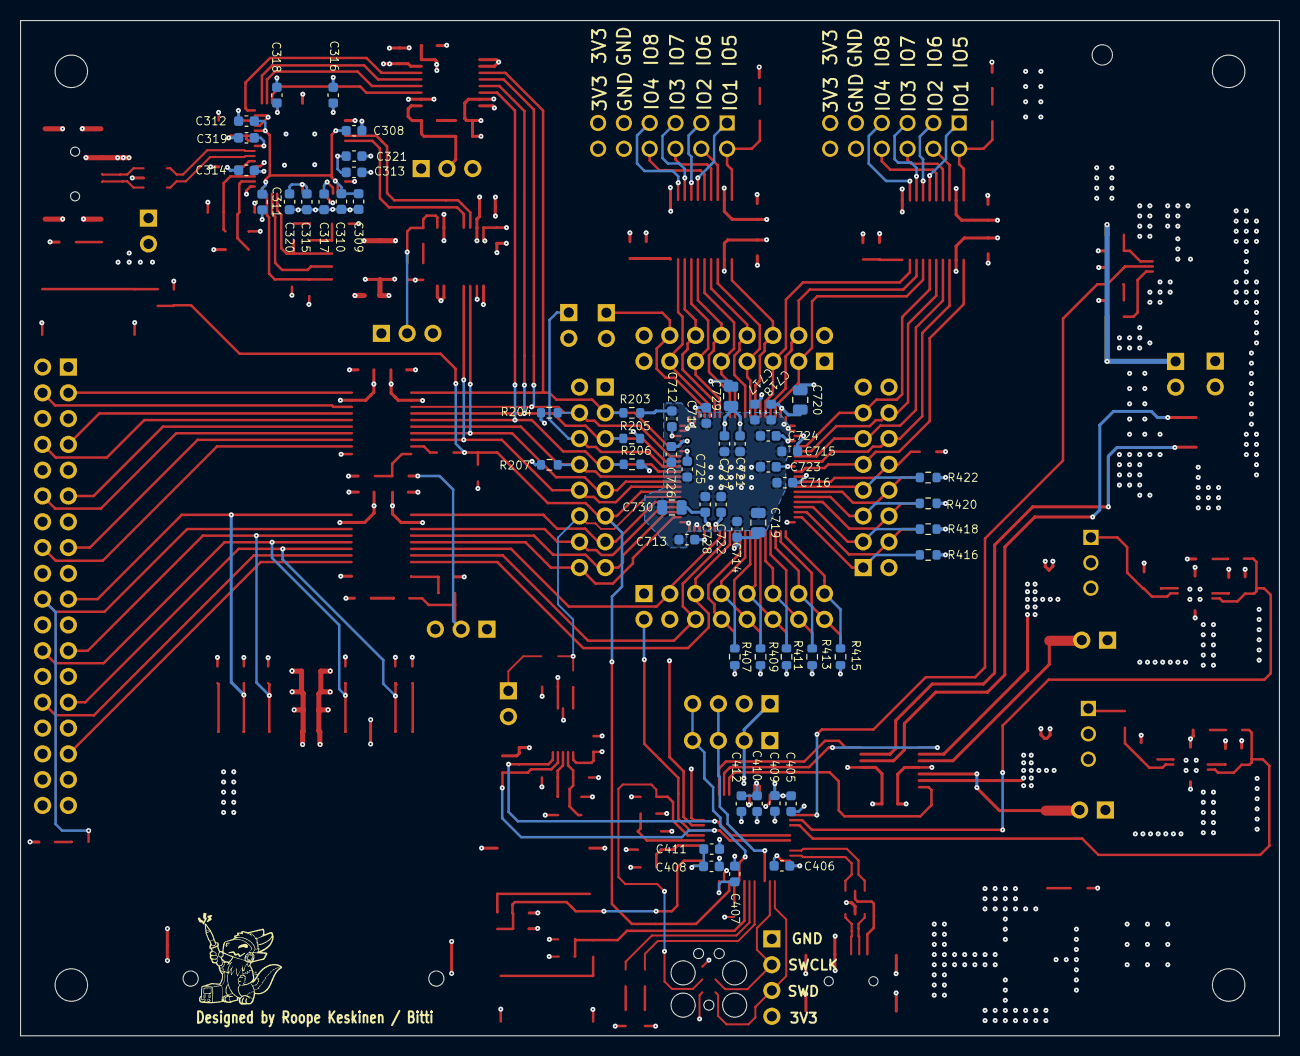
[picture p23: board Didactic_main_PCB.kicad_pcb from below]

Board: 4 copper layers, 124.0 x 100.0 mm, 250 parts (56 on the bottom side), 181 nets.

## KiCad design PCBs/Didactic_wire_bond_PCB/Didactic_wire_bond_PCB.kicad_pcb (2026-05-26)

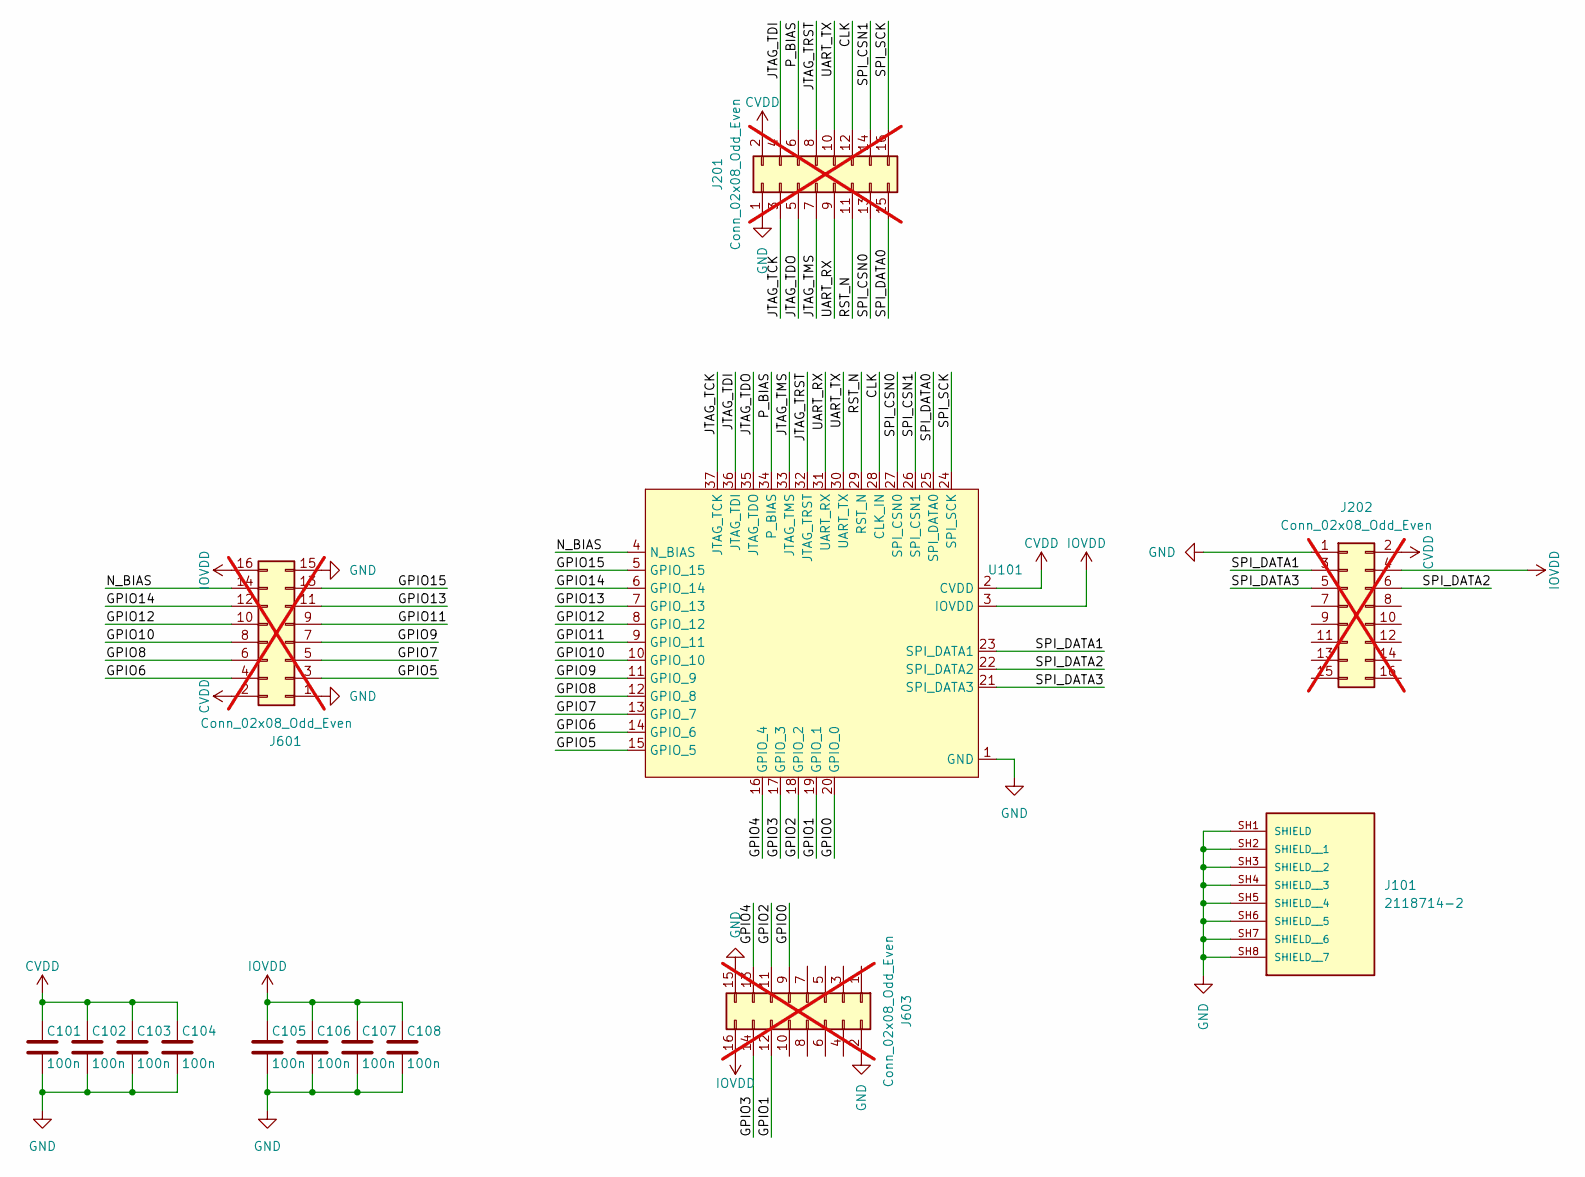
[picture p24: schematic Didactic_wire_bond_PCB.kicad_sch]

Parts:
C101, C102, C103, C104, C105, C106, C107, C108: 100n; C_0402_1005Metric
J101: 2118714-2; TE_2118714-2; PARTREV A2
J201, J202, J601, J603: Conn_02x08_Odd_Even; PinHeader_2x08_P2.54mm_Vertical; not fitted
U101: Didactic_WB

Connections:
/CLK: J201.12, U101.28 (CLK_IN)
/GPIO0: J603.9, U101.20 (GPIO_0)
/GPIO1: J603.12, U101.19 (GPIO_1)
/GPIO2: J603.11, U101.18 (GPIO_2)
/GPIO3: J603.14, U101.17 (GPIO_3)
/GPIO4: J603.13, U101.16 (GPIO_4)
/GPIO5: J601.3, U101.15 (GPIO_5)
/GPIO6: J601.4, U101.14 (GPIO_6)
/GPIO7: J601.5, U101.13 (GPIO_7)
/GPIO8: J601.6, U101.12 (GPIO_8)
/GPIO9: J601.7, U101.11 (GPIO_9)
/GPIO10: J601.8, U101.10 (GPIO_10)
/GPIO11: J601.9, U101.9 (GPIO_11)
/GPIO12: J601.10, U101.8 (GPIO_12)
/GPIO13: J601.11, U101.7 (GPIO_13)
/GPIO14: J601.12, U101.6 (GPIO_14)
/GPIO15: J601.13, U101.5 (GPIO_15)
/JTAG_TCK: J201.3, U101.37 (JTAG_TCK)
/JTAG_TDI: J201.4, U101.36 (JTAG_TDI)
/JTAG_TDO: J201.5, U101.35 (JTAG_TDO)
/JTAG_TMS: J201.7, U101.33 (JTAG_TMS)
/JTAG_TRST: J201.8, U101.32 (JTAG_TRST)
/N_BIAS: J601.14, U101.4 (N_BIAS)
/P_BIAS: J201.6, U101.34 (P_BIAS)
/RST_N: J201.11, U101.29 (RST_N)
/SPI_CSN0: J201.13, U101.27 (SPI_CSN0)
/SPI_CSN1: J201.14, U101.26 (SPI_CSN1)
/SPI_DATA0: J201.15, U101.25 (SPI_DATA0)
/SPI_DATA1: J202.3, U101.23 (SPI_DATA1)
/SPI_DATA2: J202.6, U101.22 (SPI_DATA2)
/SPI_DATA3: J202.5, U101.21 (SPI_DATA3)
/SPI_SCK: J201.16, U101.24 (SPI_SCK)
/UART_RX: J201.9, U101.31 (UART_RX)
/UART_TX: J201.10, U101.30 (UART_TX)
CVDD: C101.1, C102.1, C103.1, C104.1, J201.2, J202.2, J601.2, U101.2 (CVDD)
GND: C101.2, C102.2, C103.2, C104.2, C105.2, C106.2, C107.2, C108.2, J101.SH1 (SHIELD), J101.SH2 (SHIELD__1), J101.SH3 (SHIELD__2), J101.SH4 (SHIELD__3), J101.SH5 (SHIELD__4), J101.SH6 (SHIELD__5), J101.SH7 (SHIELD__6), J101.SH8 (SHIELD__7), J201.1, J202.1, J601.1, J601.15, J603.2, J603.15, U101.1 (GND)
IOVDD: C105.1, C106.1, C107.1, C108.1, J202.4, J601.16, J603.16, U101.3 (IOVDD)

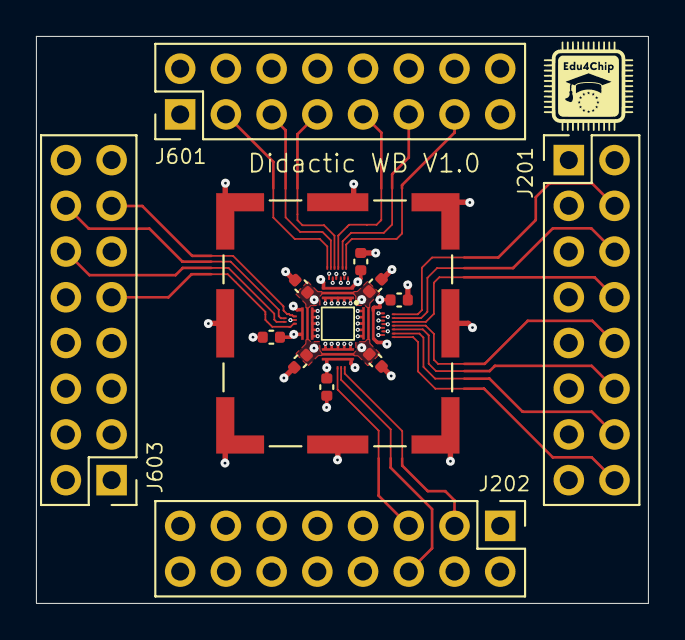
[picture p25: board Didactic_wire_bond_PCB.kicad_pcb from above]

Board: 6 copper layers, 34.0 x 31.5 mm, 14 parts (0 on the bottom side), 37 nets.

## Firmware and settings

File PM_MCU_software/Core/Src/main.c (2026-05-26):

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
/* Includes ------------------------------------------------------------------*/
#include "main.h"
#include "adc.h"
#include "dma.h"
#include "i2c.h"
#include "iwdg.h"
#include "usb_device.h"
#include "gpio.h"

/* USER CODE BEGIN Includes */
#include <stdarg.h> //for va_list var arg functions
#include "si5351.h"
#include "powerRails.h"
#include "usefulFunctions.h"
#include "flash.h"
/* USER CODE END Includes */


void SystemClock_Config(void);
/* USER CODE BEGIN PFP */
void USBprintf(const char *fmt, ...);

uint8_t USBReceiveBuffer[64];
uint32_t lastPWRButtonTime = 0;
volatile uint8_t startUpPressed = 0;
volatile uint8_t startClock = 0;
volatile uint8_t stopClock = 0;

volatile uint16_t adcBufferVoltage[SAMPLE_COUNT * POWER_RAIL_COUNT]; //Buffer for reading ADC1 values (Voltages)
volatile uint16_t adcBufferCurrent[SAMPLE_COUNT * CURRENT_CHANNEL_COUNT]; //Buffer for reading ADC2 values (Currents)

extern powerRail_t *powerRails[POWER_RAIL_COUNT];


/* USER CODE END PFP */

/**
  * @brief  The application entry point.
  * @retval int
  */
int main(void)
{

  /* MCU Configuration--------------------------------------------------------*/

  /* Reset of all peripherals, Initializes the Flash interface and the Systick. */
  HAL_Init();

  /* Configure the system clock */
  SystemClock_Config();

  /* Initialize all configured peripherals */
  MX_GPIO_Init();
  MX_DMA_Init();
  MX_USB_Device_Init();
  MX_ADC1_Init();
  MX_ADC2_Init();
  MX_I2C2_Init();
  MX_I2C1_Init();
  MX_IWDG_Init();
  /* USER CODE BEGIN 2 */
	//Set Didactic reset
	setReset(0);
	HAL_ADCEx_Calibration_Start(&hadc1, ADC_SINGLE_ENDED);
	HAL_ADCEx_Calibration_Start(&hadc2, ADC_SINGLE_ENDED);

	smartUSBPrint("Didactic board powered up \r\n");
	HAL_ADC_Start_DMA(&hadc1, (uint32_t*) adcBufferVoltage, POWER_RAIL_COUNT*SAMPLE_COUNT);
	HAL_ADC_Start_DMA(&hadc2, (uint32_t*) adcBufferCurrent, SAMPLE_COUNT * CURRENT_CHANNEL_COUNT);

	printInfo();

	saveDefaultValues(powerRails, POWER_RAIL_COUNT);
	if( *(__IO uint32_t*)0x0801F800 !=  0xDEADBEEF){
		restoreDefaultValues(powerRails, POWER_RAIL_COUNT);
		smartUSBPrint("\r\n Can't load config from Flash. Loading default config\r\n");
	}
	else{
		readPowerRailDataFromFlash(powerRails, POWER_RAIL_COUNT);
	}

  /* USER CODE END 2 */

  /* Infinite loop */
  /* USER CODE BEGIN WHILE */
	while (1) {
		HAL_IWDG_Refresh(&hiwdg);
		//Logic for handling power button presses
		if (startUpPressed) {
			startUpPressed = 0;

			if (getPowerStatus() == OFF) {
				startUp();
				setPrintInfoFlag();
			} else if (getPowerStatus() == ON) {
				turnOff();
				setPrintInfoFlag();
			}
		}

		if(startClock == 1){
			startClock = 0;
			enableClock();
		}
		else if(stopClock == 1){
			stopClock = 0;
			disableClock();
		}

		greenLEDLogic();
		redLEDLogic();
		printVoltages();
		smartUSBPrintNext();

    /* USER CODE END WHILE */

    /* USER CODE BEGIN 3 */
	}
  /* USER CODE END 3 */
}

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
/* USER CODE BEGIN 4 */


/**
 * @bried callback function for GPIO interrupt
 * @aram GPIO_Pin the pin which caused the interrupt
 */
void HAL_GPIO_EXTI_Callback(uint16_t GPIO_Pin) {
	if (GPIO_Pin == PWR_BTN_Pin) {
		if (HAL_GetTick() - lastPWRButtonTime > 1500) { //Debounce
			lastPWRButtonTime = HAL_GetTick();
			startUpPressed = 1;
		}
	}
}

/* USER CODE END 4 */
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


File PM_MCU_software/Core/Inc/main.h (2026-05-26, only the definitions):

#define USER_BTN_Pin GPIO_PIN_13
#define USER_BTN_GPIO_Port GPIOC
#define USER_BTN_EXTI_IRQn EXTI15_10_IRQn
#define CVDD_VOLTAGE_Pin GPIO_PIN_0
#define CVDD_VOLTAGE_GPIO_Port GPIOA
#define IOVDD_VOLTAGE_Pin GPIO_PIN_1
#define IOVDD_VOLTAGE_GPIO_Port GPIOA
#define IOVDD3V3_VOLTAGE_Pin GPIO_PIN_2
#define IOVDD3V3_VOLTAGE_GPIO_Port GPIOA
#define IOVDD3V3_CURRENT_Pin GPIO_PIN_5
#define IOVDD3V3_CURRENT_GPIO_Port GPIOA
#define CVDD_CURRENT_Pin GPIO_PIN_6
#define CVDD_CURRENT_GPIO_Port GPIOA
#define IOVDD_CURRENT_Pin GPIO_PIN_7
#define IOVDD_CURRENT_GPIO_Port GPIOA
#define EN_IOVDD3V3_Pin GPIO_PIN_12
#define EN_IOVDD3V3_GPIO_Port GPIOB
#define EN_CVDD_Pin GPIO_PIN_13
#define EN_CVDD_GPIO_Port GPIOB
#define EN_IOVDD_Pin GPIO_PIN_14
#define EN_IOVDD_GPIO_Port GPIOB
#define LED_GREEN_Pin GPIO_PIN_4
#define LED_GREEN_GPIO_Port GPIOB
#define LED_RED_Pin GPIO_PIN_5
#define LED_RED_GPIO_Port GPIOB
#define PWR_BTN_Pin GPIO_PIN_6
#define PWR_BTN_GPIO_Port GPIOB
#define PWR_BTN_EXTI_IRQn EXTI9_5_IRQn
#define DIDACTIC_RSTN_Pin GPIO_PIN_9
#define DIDACTIC_RSTN_GPIO_Port GPIOB

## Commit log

2026-05-26 Added power management MCU software
2026-05-26 Added Didactic main PCB kicad project
    [2118714-2.step, 218-6LPST.stp, 2908-05WB-MG.step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]
2026-05-26 Added didactic wire bond PCB kicad project
    [Didactic_WB-all-pos.csv, Didactic_main_PCB-B_Cu.gbr, Didactic_main_PCB-B_Mask.gbr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]
2026-07-29 fixed 3V3 IO EN silkscreen and changed STATUS led to green
    [Didactic_main_PCB.kicad_pcb, Didactic_main_PCB.kicad_sch, PowerMCU.kicad_sch]

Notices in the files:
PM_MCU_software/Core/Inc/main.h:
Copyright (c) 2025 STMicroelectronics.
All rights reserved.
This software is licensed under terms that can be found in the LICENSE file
